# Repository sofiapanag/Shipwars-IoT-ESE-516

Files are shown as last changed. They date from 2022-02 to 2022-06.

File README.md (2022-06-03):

# SHIPWARS

## DEVPOST LINK
https://devpost.com/software/ship-wars

## Youtube LINK
https://www.youtube.com/watch?v=rYZES1QMRgo&feature=emb_imp_woyt

## Compilation
A recreation of battleship game using embedded system. The game can be played remotely by 2 players using identical hardware (PCBs) we designed.

For Altium PCB design files - refer to "Altium_design_Shipwars"

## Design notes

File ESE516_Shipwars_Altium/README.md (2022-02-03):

# ESE516_Starter_PCB
This is the starter PCB (Altium) for the class ESE516

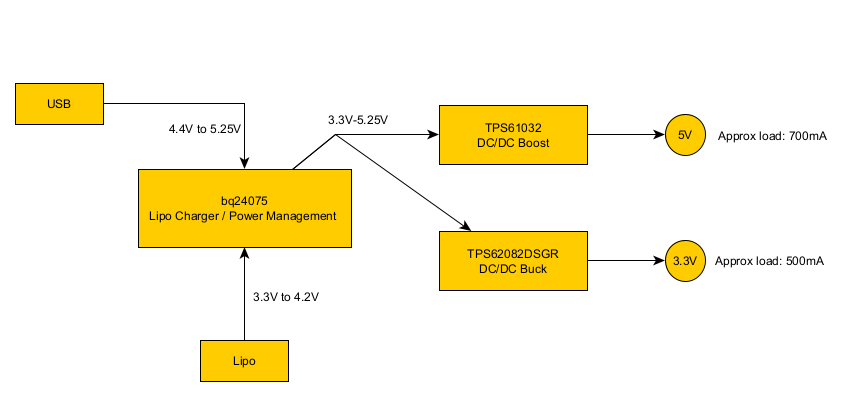
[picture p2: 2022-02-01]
Power_architect/power_management.png

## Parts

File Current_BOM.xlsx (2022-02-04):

Group Name
Group Member # 1 | Sofia Panagopoulou
Group Member # 2 | Pattana Soranasataporn
Component | Manufacturer part number (MPN) | Manufacturer | Digikey PN | Voltage(Min) | Voltage(Max) | Power - Current Consumption, typical (mA) | Quiescent current (mA) | Interface to MCU | Qty | Cost QTY1 | Cost QTY 1K | Dev Board Link (Required) | Dev Board Price | Comments | IN Altium lib?
MCU and WiFI | ATSAMW25H18-MR210PB1952 | microchip | ATSAMW25H18-MR210PB1952-ND | 2.7V | 4.3V | 230 | 0.02 | N/A | 2 | 12.05 | 10.92 | https://www.digikey.com/product-detail/en/microchip-technology/ATSAMW25-XPRO/ATSAMW25-XPRO-ND/5235960 | 41.04 |  | Provided
Adafruit NeoTrellis RGB Driver PCB for 4x4 Keypad | 3954 | Adafruit | 1528-2712-ND | 3.7V | 5.5V | 320 | 0 | I2C | 4 | 12.5 | 12.5 | https://www.digikey.com/en/products/detail/adafruit-industries-llc/3954/9658070 | 12.5 | External connect - not in PCB | External
LSM6DSO Accelero | LSM6DSOTR | STMicroelectronics | 497-18181-2-ND | 1.71V | 3.6V | 0.55 | 0 | I2C | 2 | 5.46 | N/A | https://www.digikey.com/en/products/detail/sparkfun-electronics/SEN-18020/14313960 | 11.95 |  | Y
 | GRM155R71C104KA88D | Murata | 490-3261-2-ND |  |  |  |  |  |  |  |  |  |  | any Generic Capacitor
Joystick, 2 - Axis Analog (Resistive) Output | COM-09032 | Sparkfun | 1528-1730-ND | 3.3V | 5V |  |  | 2x ADC, 1XGPIO | 2 | 3.95 | N/A | https://www.sparkfun.com/products/9110 | 1.95 |  | N - import from SnapEDA to Schematics.SchLib
Power
Lipo Charger | bq24075 | Texas Instrument | 296-38874-2-ND | 4.35V | 26V |  |  |  | 2 | 2.53 | 1.41 | https://www.digikey.com/en/products/detail/texas-instruments/BQ24075EVM/2047272 | 118.8 | Power | Y
DC/DC boost | TPS61032RSAR | Texas Instrument | 296-16662-2-ND | 1.8V | 5.5V |  |  |  | 2 | 3.13 | 1.95 | https://www.digikey.com/en/products/detail/texas-instruments/TPS61032EVM-208/562072 | 58.8 | Power | Y
 | C0603C105K8PACTU C0603C105K8PACTU | Kemet | 399-C0603C105K8PAC7867TR-ND |  |  |  |  |  | 1 |  |  |  |  |  | Y
 | C1608X5R1A156M080AC | TDK | 445-9117-2-ND |  |  |  |  |  | 1 |  |  |  |  |  | N - import from SnapEDA to CommonComponents.SchLib
 | GRM155R71A104KA01D | Murata | 490-6321-2-ND |  |  |  |  |  | 1 |  |  |  |  |  | Y
 | 6TPB470M | Panasonic | P16619CT-ND |  |  |  |  |  | 1 |  |  |  |  |  | N - import from SnapEDA to CommonComponents.SchLib
 | DR127-2R2-R | Eaton | 513-1220-1-ND |  |  |  |  |  | 1 |  |  |  |  |  | N - import from SnapEDA to CommonComponents.SchLib
 | RC0603FR-07390KL | Yageo | 311-390KHRTR-ND |  |  |  |  |  | 1 |  |  |  |  |  | N - import from SnapEDA to CommonComponents.SchLib
 | CRCW04022M15FKED | Vishay-Dale | 541-2.15MLCT-ND |  |  |  |  |  | 2 |  |  |  |  |  | Y
DC/DC buck | TPS62082DSGR | Texas Instrument | 296-49331-1-ND | 2.3V | 6V |  |  |  | 2 | 1.73 | 0.97 | N/A | N/A | Power | Y
 | GRJ155R60J106ME11D | Murata | 490-13211-1-ND |  |  |  |  |  |  |  |  |  |  |  | Y
 | GRM188R60J226MEA0D | Murata | 490-7611-2-ND |  |  |  |  |  |  |  |  |  |  |  | Y
 | 744311100 | Wurth Elektronik | 732-4177-1-ND |  |  |  |  |  |  |  |  |  |  |  | Y
 | RC0603FR-07178KL | Yageo | 311-178KHRCT-ND |  |  |  |  |  |  |  |  |  |  |  | Y
LiPo Battery | USE-702528-500PCBJST | US Electronics Inc. | 3544-USE-702528-500PCBJST-ND | 3V | 3.7V |  |  |  | 2 | 6.49 | 5.75 | N/A |  |  | External
Other peripherals
Piezoelectric Buzzers | PS1240P02BT | TDK Corporation | 445-2525-1-ND | 3V | 3V |  |  |  | 1 | 0.61 | N/A |  |  |  | N - import from SnapEDA to Schematics.SchLib
 | 2SC1815 | Central Semiconductor Corp | 1514-2SC1815PBFREE-ND |  |  |  |  |  |  |  |  |  |  | any 2SC1815 equivalent | N - import from SnapEDA to CommonComponents.SchLib
 |  |  |  |  | Total mA | 870.55 |  | Total |  | 120.68

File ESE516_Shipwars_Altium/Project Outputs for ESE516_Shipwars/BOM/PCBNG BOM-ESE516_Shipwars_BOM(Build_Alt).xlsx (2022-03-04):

Line # | Name | Description | Designator | Manufacturer 1 | Manufacturer Part Number 1 | Manufacturer Lifecycle 1 | Supplier 1 | Supplier Part Number 1 | Supplier Unit Price 1 | Supplier Subtotal 1 | Fitted
1 | PTS810 SJK 250 SMTR LFS | SWITCH TACTILE SPST-NO 0.05A 16V Tactile Switch SPST-NO Top Actuated Surface Mount | B1 | ITT C&K | PTS810SJM250SMTRLFS | Volume Production | Digi-Key | CKN10502CT-ND | 0 | 0 | Fitted
1 | PTS810 SJK 250 SMTR LFS | SWITCH TACTILE SPST-NO 0.05A 16V Tactile Switch SPST-NO Top Actuated Surface Mount | B3 | ITT C&K | PTS810SJM250SMTRLFS | Volume Production | Digi-Key | CKN10502CT-ND | 0 | 0 | Fitted
2 | CAP 100nF 16V 0603(1608) | CAP 100nF 16V ±10% 0603 (1608 Metric) Thickness 1mm SMD | C1 | Yageo | CC0603KPX7R7BB104 | Volume Production | Digi-Key | 311-1335-1-ND | 0.1 | 0.4 | Fitted
2 | CAP 100nF 16V 0603(1608) | CAP 100nF 16V ±10% 0603 (1608 Metric) Thickness 1mm SMD | C3 | Yageo | CC0603KPX7R7BB104 | Volume Production | Digi-Key | 311-1335-1-ND | 0.1 | 0.4 | Fitted
2 | CAP 100nF 16V 0603(1608) | CAP 100nF 16V ±10% 0603 (1608 Metric) Thickness 1mm SMD | C7 | Yageo | CC0603KPX7R7BB104 | Volume Production | Digi-Key | 311-1335-1-ND | 0.1 | 0.4 | Fitted
2 | CAP 100nF 16V 0603(1608) | CAP 100nF 16V ±10% 0603 (1608 Metric) Thickness 1mm SMD | C15 | Yageo | CC0603KPX7R7BB104 | Volume Production | Digi-Key | 311-1335-1-ND | 0.1 | 0.4 | Fitted
3 | C1608X5R1A226M080AC | Chip Capacitor, 22 uF, +/- 20%, 10 V, -55 to 85 degC, 0603 (1608 Metric), RoHS, Tape and Reel | C1bst | TDK | C1608X5R1A226M080AC | Volume Production | Digi-Key | 445-9077-2-ND | 0.11594 | 463.76 | Fitted
4 | CAP 10nF 16V 0603(1608) | CAP 10nF 16V ±10% 0603 (1608 Metric) Thickness 1mm SMD | C2 | Yageo | CC0603KRX7R7BB103 | Volume Production | Digi-Key | 311-3369-1-ND | 0.1 | 0.1 | Fitted
5 | GRM155R71A104KA01D | Chip Capacitor, 0.1 uF, +/- 10%, 10 V, -55 to 125 degC, 0402 (1005 Metric), RoHS, Tape and Reel | C2bst | Murata | GRM155R71A104KA01D | Unknown | Digi-Key | 490-6321-1-ND | 0.1 | 0.1 | Fitted
6 | C0603C105K8PACTU |  | C3bst | KEMET | C0603C105K8PACTU | Volume Production | Digi-Key | 399-C0603C105K8PAC7867CT-ND | 0.1 | 0.1 | Fitted
7 | CAP 4.7uF 16V 0805(2012) | CAP 4.7uF 16V -20% to +80% 0805 (2012 Metric) Thickness 1.45mm SMD | C4 | Yageo | CC0805ZKY5V7BB475 | Volume Production | Digi-Key | 311-1907-1-ND | 0.25 | 0.75 | Fitted
7 | CAP 4.7uF 16V 0805(2012) | CAP 4.7uF 16V -20% to +80% 0805 (2012 Metric) Thickness 1.45mm SMD | C25 | Yageo | CC0805ZKY5V7BB475 | Volume Production | Digi-Key | 311-1907-1-ND | 0.25 | 0.75 | Fitted
7 | CAP 4.7uF 16V 0805(2012) | CAP 4.7uF 16V -20% to +80% 0805 (2012 Metric) Thickness 1.45mm SMD | C26 | Yageo | CC0805ZKY5V7BB475 | Volume Production | Digi-Key | 311-1907-1-ND | 0.25 | 0.75 | Fitted
8 | 470uF 6.3V | Cap Tant Solid 470uF 6.3V D4 CASE 20% (7.3 X 4.3 X 3.8mm) 2917(7343) SMD 7343 0.035 Ohm 105 C Embossed T/R 6TPB470M | C4bst | Panasonic | 6TPB470M | Volume Production | Digi-Key | P16619CT-ND | 2.8 | 2.8 | Fitted
9 | CAP 47pF 16V 0603(1608) | CAP 47pF 16V ±0.5pF 0603 (1608 Metric) Thickness 1mm SMD | C5 | Yageo | CC0603KPX7R7BB473 | Volume Production | Digi-Key | 13-CC0603KPX7R7BB473CT-ND | 0.1 | 0.2 | Fitted
9 | CAP 47pF 16V 0603(1608) | CAP 47pF 16V ±0.5pF 0603 (1608 Metric) Thickness 1mm SMD | C6 | Yageo | CC0603KPX7R7BB473 | Volume Production | Digi-Key | 13-CC0603KPX7R7BB473CT-ND | 0.1 | 0.2 | Fitted
10 | CAP 10uF 16V 0805(2012) | CAP 10uF 16V ±10% 0805 (2012 Metric) Thickness 1.45mm SMD | C10 | Yageo | CC0805MKX7R7BB106 | Unknown | Digi-Key | 311-3508-1-ND | 0.64 | 1.28 | Fitted
10 | CAP 10uF 16V 0805(2012) | CAP 10uF 16V ±10% 0805 (2012 Metric) Thickness 1.45mm SMD | C11 | Yageo | CC0805MKX7R7BB106 | Unknown | Digi-Key | 311-3508-1-ND | 0.64 | 1.28 | Fitted
11 | CAP 1uF 16V 0603(1608) | CAP 1uF 16V ±5% 0603 (1608 Metric) Thickness 1mm SMD | C12 | Yageo | CC0603JRX7R7BB105 | Unknown | Digi-Key | 311-3485-2-ND | 0.0475 | 190 | Fitted
11 | CAP 1uF 16V 0603(1608) | CAP 1uF 16V ±5% 0603 (1608 Metric) Thickness 1mm SMD | C18 | Yageo | CC0603JRX7R7BB105 | Unknown | Digi-Key | 311-3485-2-ND | 0.0475 | 190 | Fitted
11 | CAP 1uF 16V 0603(1608) | CAP 1uF 16V ±5% 0603 (1608 Metric) Thickness 1mm SMD | C24 | Yageo | CC0603JRX7R7BB105 | Unknown | Digi-Key | 311-3485-2-ND | 0.0475 | 190 | Fitted
12 | CAP 18pF 16V 0603(1608) | CAP 18pF 16V ±5% 0603 (1608 Metric) Thickness 1mm SMD | C13 | KEMET | C0603C180J4GACTU | Volume Production | Digi-Key | 399-C0603C180J4GAC7867CT-ND | 0.25 | 0.5 | Fitted
12 | CAP 18pF 16V 0603(1608) | CAP 18pF 16V ±5% 0603 (1608 Metric) Thickness 1mm SMD | C14 | KEMET | C0603C180J4GACTU | Volume Production | Digi-Key | 399-C0603C180J4GAC7867CT-ND | 0.25 | 0.5 | Fitted
13 | CC0402KRX7R7BB104 | CAP CER 0.1UF 16V X7R 0402 | C16 | Yageo | CC0402KRX7R7BB104 | Volume Production | Digi-Key | 311-1338-2-ND | 0.00554 | 55.4 | Fitted
13 | CC0402KRX7R7BB104 | CAP CER 0.1UF 16V X7R 0402 | C17 | Yageo | CC0402KRX7R7BB104 | Volume Production | Digi-Key | 311-1338-2-ND | 0.00554 | 55.4 | Fitted
14 | 10uF 6.3V | Capacitor Ceramic Mlcc 0402 10UF 6.3V SMD | C8 | Murata | GRJ155R60J106ME11D | Volume Production | Digi-Key | 490-13211-1-ND | 0.2 | 0.2 | Fitted
15 | GRM188R60J226MEA0D | Chip Multilayer Ceramic Capacitors for General Purpose, 0603, 22uF, X5R, 15%, 20%, 6.3V | Coutbck | Murata | GRM188R60J226MEA0D | Volume Production | Digi-Key | 490-7611-2-ND | 0.0418 | 167.2 | Fitted
16 | PRTR5V0U2X,215 | Ultra Low Capacitance Double Rail-to-Rail ESD Protection Diode, 5.5 V, 1 pF, -40 to 85 degC, 4-Pin SOT143B, RoHS, Tape and Reel | D1 | Nexperia | PRTR5V0U2X,215 | Unknown | Mouser | 771-PRTR5V0U2X-T/R | 0.52 | 0.52 | Fitted
17 | LTST-C170CKT | LED Uni-Color Red, 100 mW, 200 mA, -55 to 85 degC, 2-Pin SMD, RoHS, Tape and Reel | D3 | Lumex | SML-LX0805SIC-TR | Volume Production | Digi-Key | 67-1636-1-ND | 0.61 | 1.83 | Fitted
17 | LTST-C170CKT | LED Uni-Color Red, 100 mW, 200 mA, -55 to 85 degC, 2-Pin SMD, RoHS, Tape and Reel | D5 | Lumex | SML-LX0805SIC-TR | Volume Production | Digi-Key | 67-1636-1-ND | 0.61 | 1.83 | Fitted
17 | LTST-C170CKT | LED Uni-Color Red, 100 mW, 200 mA, -55 to 85 degC, 2-Pin SMD, RoHS, Tape and Reel | DS3 | Lumex | SML-LX0805SIC-TR | Volume Production | Digi-Key | 67-1636-1-ND | 0.61 | 1.83 | Fitted
18 | LTST-C170GKT | LED Uni-Color Green, 100 mW, 120 mA, -55 to 85 degC, 2-Pin SMD, RoHS, Tape and Reel | D4 | Vishay Lite-On | LTST-C170GKT | Volume Production | Digi-Key | 160-1179-2-ND | 0.05267 | 158.01 | Fitted
18 | LTST-C170GKT | LED Uni-Color Green, 100 mW, 120 mA, -55 to 85 degC, 2-Pin SMD, RoHS, Tape and Reel | DS1 | Vishay Lite-On | LTST-C170GKT | Volume Production | Digi-Key | 160-1179-2-ND | 0.05267 | 158.01 | Fitted
18 | LTST-C170GKT | LED Uni-Color Green, 100 mW, 120 mA, -55 to 85 degC, 2-Pin SMD, RoHS, Tape and Reel | DS2 | Vishay Lite-On | LTST-C170GKT | Volume Production | Digi-Key | 160-1179-2-ND | 0.05267 | 158.01 | Fitted
19 | MPZ1608S300ATAH0 | FERRITE BEAD 30 OHM 0603 1LN | FB2 | Murata | BLM18PG300SN1D | Volume Production | Digi-Key | 490-1035-1-ND | 0.1 | 0.1 | Fitted
20 | BLM21PG221SN1D | Chip Ferrite Bead for Power Lines, 220 Ohm, 2000 mA, -55 to 125 degC, 2 x 1.25 x 1.05 mm SMD, Tape and Reel | FB1 | Bourns | MH2029-221Y | Volume Production | Digi-Key | MH2029-221YCT-ND | 0.1 | 0.1 | Fitted
21 | TPS61032RSAR | 5-V Output, 1-A, 96% Efficient Boost Converter w/20uA Iq in TSSOP-16 16-QFN -40 to 85 | U2 | Texas Instruments | TPS61032RSAR | Volume Production | Digi-Key | 296-16662-1-ND | 3.13 | 3.13 | Fitted
22 | ZX62R-B-5P | Connector; USBMicro-B,Reverse type, SMT; 5 Position; Right Angle | J1 | Hirose | ZX62R-B-5P(30) | Volume Production | Digi-Key | H125274CT-ND | 1.02 | 1.02 | Fitted
23 | S4B-PH-SM4-TB(LF)(SN) | JST (JAPAN SOLDERLESS TERMINALS) - S4B-PH-SM4-TB(LF)(SN) - Wire-To-Board Connector, 2 mm, 4 Contacts, Header, PH Series, Surface Mount, 1 Rows | J3 | JST | S4B-PH-SM4-TB(LF)(SN) | Volume Production | Digi-Key | 455-1751-2-ND | 0.38039 | 380.39 | Fitted
23 | S4B-PH-SM4-TB(LF)(SN) | JST (JAPAN SOLDERLESS TERMINALS) - S4B-PH-SM4-TB(LF)(SN) - Wire-To-Board Connector, 2 mm, 4 Contacts, Header, PH Series, Surface Mount, 1 Rows | J4 | JST | S4B-PH-SM4-TB(LF)(SN) | Volume Production | Digi-Key | 455-1751-2-ND | 0.38039 | 380.39 | Fitted
24 | 744311100 | SMD Flat Wire High Current Inductor WE-HCI, L=1.00 µH | L1bck | Wurth Electronics | 744311100 | Volume Production | Digi-Key | 732-4177-1-ND | 3.69 | 3.69 | Fitted
25 | 2.2uH | Ind Power Shielded Wirewound 2.2uH 20% 100KHz Ferrite 12.5A T/R DR127-2R2-R | L1bst | Eaton Cooper | DR127-2R2-R | Volume Production | Digi-Key | 513-1220-1-ND | 1.5 | 1.5 | Fitted
26 | PS1240P02BT | TDK - PS1240P02BT - BUZZER, PIEZO, 70DB, 12.2MM | LS | TDK | PS1240P02BT | Volume Production | Digi-Key | 445-2525-1-ND | 0.62 | 0.62 | Fitted
27 | 640456-3 | Male Header, Pitch 2.54 mm, 1 x 3 Position, Height 10.03 mm, Tail Length 3.56 mm, -55 to 105 degC | P1 | TE Connectivity | 640456-3 | Volume Production | Mouser | 571-6404563 | 0.2 | 0.2 | Fitted
28 | 50V 150mA | Transistor GP BJT NPN 50V 150mA 3-Pin TO-92 Box 2SC1815 | Q | Central Semiconductor | 2SC1815 PBFREE | Unknown | Digi-Key | 1514-2SC1815PBFREE-ND | 0.98 | 0.98 | Fitted
29 | 27R 1% 0603(1608) | 27R 0.1W 1% 0603 (1608 Metric) SMD | R1 | Yageo | RC0603FR-0727RL | Volume Production | Digi-Key | 311-27.0HRTR-ND | 0.00312 | 15.6 | Fitted
29 | 27R 1% 0603(1608) | 27R 0.1W 1% 0603 (1608 Metric) SMD | R2 | Yageo | RC0603FR-0727RL | Volume Production | Digi-Key | 311-27.0HRTR-ND | 0.00312 | 15.6 | Fitted
29 | 27R 1% 0603(1608) | 27R 0.1W 1% 0603 (1608 Metric) SMD | R8 | Yageo | RC0603FR-0727RL | Volume Production | Digi-Key | 311-27.0HRTR-ND | 0.00312 | 15.6 | Fitted
29 | 27R 1% 0603(1608) | 27R 0.1W 1% 0603 (1608 Metric) SMD | R9 | Yageo | RC0603FR-0727RL | Volume Production | Digi-Key | 311-27.0HRTR-ND | 0.00312 | 15.6 | Fitted
29 | 27R 1% 0603(1608) | 27R 0.1W 1% 0603 (1608 Metric) SMD | R10 | Yageo | RC0603FR-0727RL | Volume Production | Digi-Key | 311-27.0HRTR-ND | 0.00312 | 15.6 | Fitted
30 | RC0603FR-07178KL |  | R1bck | Yageo | RC0603FR-07178KL | Volume Production | Digi-Key | 311-178KHRCT-ND | 0.1 | 0.1 | Fitted
31 | CRCW04022M15FKED |  | R1bst | Stackpole Electronics | RMCF0402FT2M15 | Volume Production | Digi-Key | RMCF0402FT2M15CT-ND | 0.1 | 0.2 | Fitted
31 | CRCW04022M15FKED |  | R3bst | Stackpole Electronics | RMCF0402FT2M15 | Volume Production | Digi-Key | RMCF0402FT2M15CT-ND | 0.1 | 0.2 | Fitted
32 | 390K 1% 0603(1608) | 390K 0.1W 1% 0603 (1608 Metric) SMD | R2bst | Yageo | RC0603FR-07390KL | Volume Production | Digi-Key | 311-390KHRCT-ND | 0.1 | 0.1 | Fitted
33 | 1K 1% 0603(1608) | 1K 0.1W 1% 0603 (1608 Metric) SMD | R3 | Stackpole Electronics | RMCF0603FT1K00 | Volume Production | Digi-Key | RMCF0603FT1K00TR-ND | 0.00218 | 10.9 | Fitted
33 | 1K 1% 0603(1608) | 1K 0.1W 1% 0603 (1608 Metric) SMD | R5 | Stackpole Electronics | RMCF0603FT1K00 | Volume Production | Digi-Key | RMCF0603FT1K00TR-ND | 0.00218 | 10.9 | Fitted
33 | 1K 1% 0603(1608) | 1K 0.1W 1% 0603 (1608 Metric) SMD | R6 | Stackpole Electronics | RMCF0603FT1K00 | Volume Production | Digi-Key | RMCF0603FT1K00TR-ND | 0.00218 | 10.9 | Fitted
33 | 1K 1% 0603(1608) | 1K 0.1W 1% 0603 (1608 Metric) SMD | R7 | Stackpole Electronics | RMCF0603FT1K00 | Volume Production | Digi-Key | RMCF0603FT1K00TR-ND | 0.00218 | 10.9 | Fitted
33 | 1K 1% 0603(1608) | 1K 0.1W 1% 0603 (1608 Metric) SMD | R15 | Stackpole Electronics | RMCF0603FT1K00 | Volume Production | Digi-Key | RMCF0603FT1K00TR-ND | 0.00218 | 10.9 | Fitted
33 | 1K 1% 0603(1608) | 1K 0.1W 1% 0603 (1608 Metric) SMD | R16 | Stackpole Electronics | RMCF0603FT1K00 | Volume Production | Digi-Key | RMCF0603FT1K00TR-ND | 0.00218 | 10.9 | Fitted
33 | 1K 1% 0603(1608) | 1K 0.1W 1% 0603 (1608 Metric) SMD | R18 | Stackpole Electronics | RMCF0603FT1K00 | Volume Production | Digi-Key | RMCF0603FT1K00TR-ND | 0.00218 | 10.9 | Fitted
33 | 1K 1% 0603(1608) | 1K 0.1W 1% 0603 (1608 Metric) SMD | R19 | Stackpole Electronics | RMCF0603FT1K00 | Volume Production | Digi-Key | RMCF0603FT1K00TR-ND | 0.00218 | 10.9 | Fitted
33 | 1K 1% 0603(1608) | 1K 0.1W 1% 0603 (1608 Metric) SMD | R24 | Stackpole Electronics | RMCF0603FT1K00 | Volume Production | Digi-Key | RMCF0603FT1K00TR-ND | 0.00218 | 10.9 | Fitted
33 | 1K 1% 0603(1608) | 1K 0.1W 1% 0603 (1608 Metric) SMD | R37 | Stackpole Electronics | RMCF0603FT1K00 | Volume Production | Digi-Key | RMCF0603FT1K00TR-ND | 0.00218 | 10.9 | Fitted
34 | Jumper 0603(1608) | Jumper 0603 (1608 Metric) | R4 | Stackpole Electronics | RMCF0603ZT0R00 | Volume Production | Avnet | RMCF0603ZT0R00 | 0.00142 | 7.1 | Fitted
34 | Jumper 0603(1608) | Jumper 0603 (1608 Metric) | R22 | Stackpole Electronics | RMCF0603ZT0R00 | Volume Production | Avnet | RMCF0603ZT0R00 | 0.00142 | 7.1 | Fitted
34 | Jumper 0603(1608) | Jumper 0603 (1608 Metric) | R23 | Stackpole Electronics | RMCF0603ZT0R00 | Volume Production | Avnet | RMCF0603ZT0R00 | 0.00142 | 7.1 | Fitted
34 | Jumper 0603(1608) | Jumper 0603 (1608 Metric) | R25 | Stackpole Electronics | RMCF0603ZT0R00 | Volume Production | Avnet | RMCF0603ZT0R00 | 0.00142 | 7.1 | Fitted
34 | Jumper 0603(1608) | Jumper 0603 (1608 Metric) | R27 | Stackpole Electronics | RMCF0603ZT0R00 | Volume Production | Avnet | RMCF0603ZT0R00 | 0.00142 | 7.1 | Fitted
34 | Jumper 0603(1608) | Jumper 0603 (1608 Metric) | R28 | Stackpole Electronics | RMCF0603ZT0R00 | Volume Production | Avnet | RMCF0603ZT0R00 | 0.00142 | 7.1 | Fitted
34 | Jumper 0603(1608) | Jumper 0603 (1608 Metric) | R31 | Stackpole Electronics | RMCF0603ZT0R00 | Volume Production | Avnet | RMCF0603ZT0R00 | 0.00142 | 7.1 | Fitted
34 | Jumper 0603(1608) | Jumper 0603 (1608 Metric) | R33 | Stackpole Electronics | RMCF0603ZT0R00 | Volume Production | Avnet | RMCF0603ZT0R00 | 0.00142 | 7.1 | Fitted
35 | 10K 1% 0603(1608) | 10K 0.1W 1% 0603 (1608 Metric) SMD | R11 | Stackpole Electronics | RMCF0603FT10K0 | Volume Production | Digi-Key | RMCF0603FT10K0TR-ND | 0.00218 | 10.9 | Fitted
35 | 10K 1% 0603(1608) | 10K 0.1W 1% 0603 (1608 Metric) SMD | R13 | Stackpole Electronics | RMCF0603FT10K0 | Volume Production | Digi-Key | RMCF0603FT10K0TR-ND | 0.00218 | 10.9 | Fitted
35 | 10K 1% 0603(1608) | 10K 0.1W 1% 0603 (1608 Metric) SMD | R14 | Stackpole Electronics | RMCF0603FT10K0 | Volume Production | Digi-Key | RMCF0603FT10K0TR-ND | 0.00218 | 10.9 | Fitted
35 | 10K 1% 0603(1608) | 10K 0.1W 1% 0603 (1608 Metric) SMD | R17 | Stackpole Electronics | RMCF0603FT10K0 | Volume Production | Digi-Key | RMCF0603FT10K0TR-ND | 0.00218 | 10.9 | Fitted
35 | 10K 1% 0603(1608) | 10K 0.1W 1% 0603 (1608 Metric) SMD | R26 | Stackpole Electronics | RMCF0603FT10K0 | Volume Production | Digi-Key | RMCF0603FT10K0TR-ND | 0.00218 | 10.9 | Fitted
35 | 10K 1% 0603(1608) | 10K 0.1W 1% 0603 (1608 Metric) SMD | R29 | Stackpole Electronics | RMCF0603FT10K0 | Volume Production | Digi-Key | RMCF0603FT10K0TR-ND | 0.00218 | 10.9 | Fitted
35 | 10K 1% 0603(1608) | 10K 0.1W 1% 0603 (1608 Metric) SMD | R30 | Stackpole Electronics | RMCF0603FT10K0 | Volume Production | Digi-Key | RMCF0603FT10K0TR-ND | 0.00218 | 10.9 | Fitted
35 | 10K 1% 0603(1608) | 10K 0.1W 1% 0603 (1608 Metric) SMD | R32 | Stackpole Electronics | RMCF0603FT10K0 | Volume Production | Digi-Key | RMCF0603FT10K0TR-ND | 0.00218 | 10.9 | Fitted
35 | 10K 1% 0603(1608) | 10K 0.1W 1% 0603 (1608 Metric) SMD | R34 | Stackpole Electronics | RMCF0603FT10K0 | Volume Production | Digi-Key | RMCF0603FT10K0TR-ND | 0.00218 | 10.9 | Fitted
35 | 10K 1% 0603(1608) | 10K 0.1W 1% 0603 (1608 Metric) SMD | R36 | Stackpole Electronics | RMCF0603FT10K0 | Volume Production | Digi-Key | RMCF0603FT10K0TR-ND | 0.00218 | 10.9 | Fitted
35 | 10K 1% 0603(1608) | 10K 0.1W 1% 0603 (1608 Metric) SMD | R38 | Stackpole Electronics | RMCF0603FT10K0 | Volume Production | Digi-Key | RMCF0603FT10K0TR-ND | 0.00218 | 10.9 | Fitted
36 | 100R 1% 0603(1608) | 100R 0.1W 1% 0603 (1608 Metric) SMD | R12 | Bourns | CR0603-FX-1000ELF | Volume Production | Digi-Key | CR0603-FX-1000ELFTR-ND | 0.00218 | 10.9 | Fitted
36 | 100R 1% 0603(1608) | 100R 0.1W 1% 0603 (1608 Metric) SMD | R35 | Bourns | CR0603-FX-1000ELF | Volume Production | Digi-Key | CR0603-FX-1000ELFTR-ND | 0.00218 | 10.9 | Fitted
37 | 1K13 1% 0603(1608) | 1K13 0.1W 1% 0603 (1608 Metric) SMD | R20 | Stackpole Electronics | RMCF0603FT1K13 | Volume Production | Digi-Key | RMCF0603FT1K13CT-ND | 0.017 | 0.17 | Fitted
37 | 1K13 1% 0603(1608) | 1K13 0.1W 1% 0603 (1608 Metric) SMD | R21 | Stackpole Electronics | RMCF0603FT1K13 | Volume Production | Digi-Key | RMCF0603FT1K13CT-ND | 0.017 | 0.17 | Fitted
38 | ADA_2765 | Mini 2-Axis Analog Thumbstick | S1 | Adafruit Industries | 2765 | Volume Production | Digi-Key | 1528-1730-ND | 2.5 | 2.5 | Fitted
39 | 104031-0811 | Micro SD Card, RA, -25 to 85 degC, 8-Pin SMD, RoHS, Tape and Reel | SD1 | Molex | 1040310811 | Volume Production | Digi-Key | WM6357TR-ND | 1.14 | 2278.28 | Fitted
40 | FT234XD-R | FT234XD USB to BASIC UART IC, -40 to +85 degC, 12-Pin DFN, Pb-Free, Tape and Reel | U1 | FTDI | FT234XD-R | Volume Production |  |  |  |  | Fitted
41 | 20021111-00010T4LF | CONN HEADER 10POS UNSHD VERT T/H | U3 | Amphenol ICC / FCI | 20021111-00010T4LF | Unknown | Mouser | 649-221111-00010T4LF | 0.74 | 0.74 | Fitted
42 | SAMW25H18-MR510PB | RF TXRX MODULE WIFI TRACE ANT | U4 | Microchip | ATSAMW25H18-MR510PB | Unknown | Digikey | ATSAMW25H18-MR510PB-ND |  |  | Fitted
43 | BQ24075RGTRG4 | USB-Friendly Li-Ion Battery Charger and Power-Path Management IC, Vout 5.5 V, 4.3 V, -40 to 85 degC, 16-pin QFN (RGT), Green (RoHS & no Sb/Br) | U6 | Texas Instruments | BQ24079TRGTT | Volume Production | Digi-Key | 296-BQ24079TRGTTCT-ND | 3.03 | 3.03 | Fitted
44 | TPS62082DSGR | Buck Step Down Regulator with 2.3 to 6 V Input and 3.3 V Output, -40 to 85 degC, 8-Pin WSON (DSG), Green (RoHS & no Sb/Br) | U7 | Texas Instruments | TPS62082DSGR | Volume Production | Digi-Key | 296-49331-1-ND | 1.73 | 1.73 | Fitted
45 | LSM6DSOTR | CONSUMER MEMS | U8 | STMicroelectronics | LSM6DSOTR | Unknown |  |  |  |  | Fitted
46 | ABS07-32.768KHz-T | Crystal, 32.768 kHz, 12.5 pF, -40 to 85 degC, SMD Low Profile 3.2 x 1.5 x 0.9 mm, Tape and Reel | X1 | Abracon | ABS07-32.768KHZ-T | Volume Production | Digi-Key | 535-9542-2-ND | 0.6808 | 2042.4 | Fitted

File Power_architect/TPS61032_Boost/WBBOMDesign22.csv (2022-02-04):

Part | Manufacturer | Part Number | Quantity | Price ($) | Footprint (mm²) | Description
Coutx | Kemet | C0603C105K8PACTU | 1 | 0.01 | 4.68 | Cap: 1 µF Total Derated Cap: 950 nF VDC: 10 V ESR: 1 mΩ Package: 0603
Cin | TDK | C1608X5R1A156M080AC | 1 | 0.12 | 4.68 | Cap: 15 µF Total Derated Cap: 3.7 µF VDC: 10 V ESR: 6.53 mΩ Package: 0603
Cinx | MuRata | GRM155R71A104KA01D | 1 | 0.01 | 3 | Cap: 100 nF Total Derated Cap: 100 nF VDC: 10 V ESR: 1 mΩ Package: 0402
Cout | Panasonic | 6TPB470M | 1 | 0.96 | 58.59 | Cap: 470 µF Total Derated Cap: 470 µF VDC: 6.3 V ESR: 35 mΩ Package: 7343-40
L1 | Coiltronics | DR127-2R2-R | 1 | 0.84 | 210.25 | L: 2.2 µH DCR: 4.02 mΩ IDC: 12.5 A
Rlbb | Yageo | RC0603FR-07390KL | 1 | 0.01 | 4.68 | Resistance: 390 kΩ Tolerance: 1.0% Power: 100 mW
Rlbo | Vishay-Dale | CRCW04022M15FKED | 1 | 0.01 | 3 | Resistance: 2.15 MΩ Tolerance: 1.0% Power: 63 mW
Rlbt | Vishay-Dale | CRCW04022M15FKED | 1 | 0.01 | 3 | Resistance: 2.15 MΩ Tolerance: 1.0% Power: 63 mW
U1 | Texas Instruments | TPS61032PWPR | 1 | 1.113 | 58.8

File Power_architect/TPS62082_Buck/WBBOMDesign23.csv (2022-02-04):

Part | Manufacturer | Part Number | Quantity | Price ($) | Footprint (mm²) | Description
Cin | MuRata | GRJ155R60J106ME11D | 1 | 0.02 | 3 | Cap: 10 µF Total Derated Cap: 2 µF VDC: 6.3 V ESR: 1 mΩ Package: 0402
Cout | MuRata | GRM188R60J226MEA0D | 1 | 0.05 | 4.68 | Cap: 22 µF Total Derated Cap: 7.9 µF VDC: 6.3 V ESR: 1 mΩ Package: 0603
L1 | Wurth Elektronik | 744311100 | 1 | 2.55 | 80.1 | L: 1 µH DCR: 5.06 mΩ IDC: 15 A
Rpg | Yageo | RC0603FR-07178KL | 1 | 0.01 | 4.68 | Resistance: 178 kΩ Tolerance: 1.0% Power: 100 mW
U1 | Texas Instruments | TPS62082DSGR | 1 | 0.552 | 9.61

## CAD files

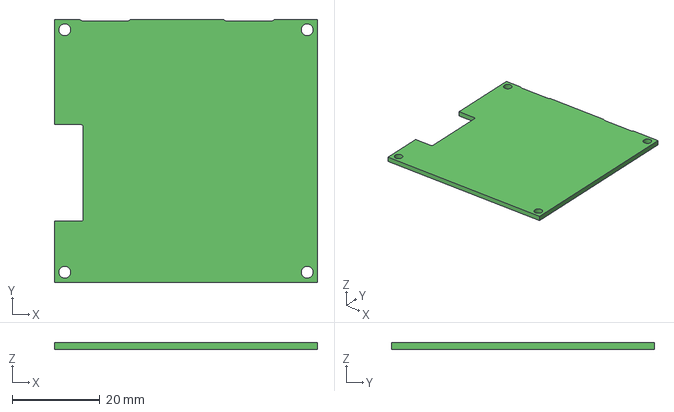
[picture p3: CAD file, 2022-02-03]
ESE516_Shipwars_Altium/Extras/BoardShape 50mmx50mm.step
60.0 x 60.0 x 1.53 mm

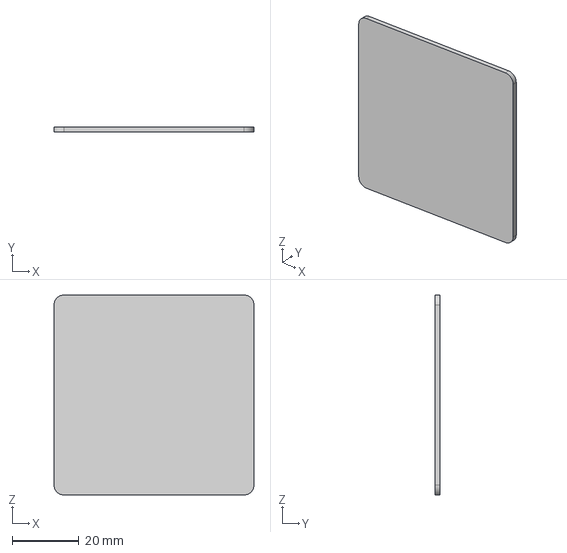
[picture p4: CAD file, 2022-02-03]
ESE516_Shipwars_Altium/Extras/BoardShape_60x60_mm.step
60.0 x 1.57 x 60.0 mm

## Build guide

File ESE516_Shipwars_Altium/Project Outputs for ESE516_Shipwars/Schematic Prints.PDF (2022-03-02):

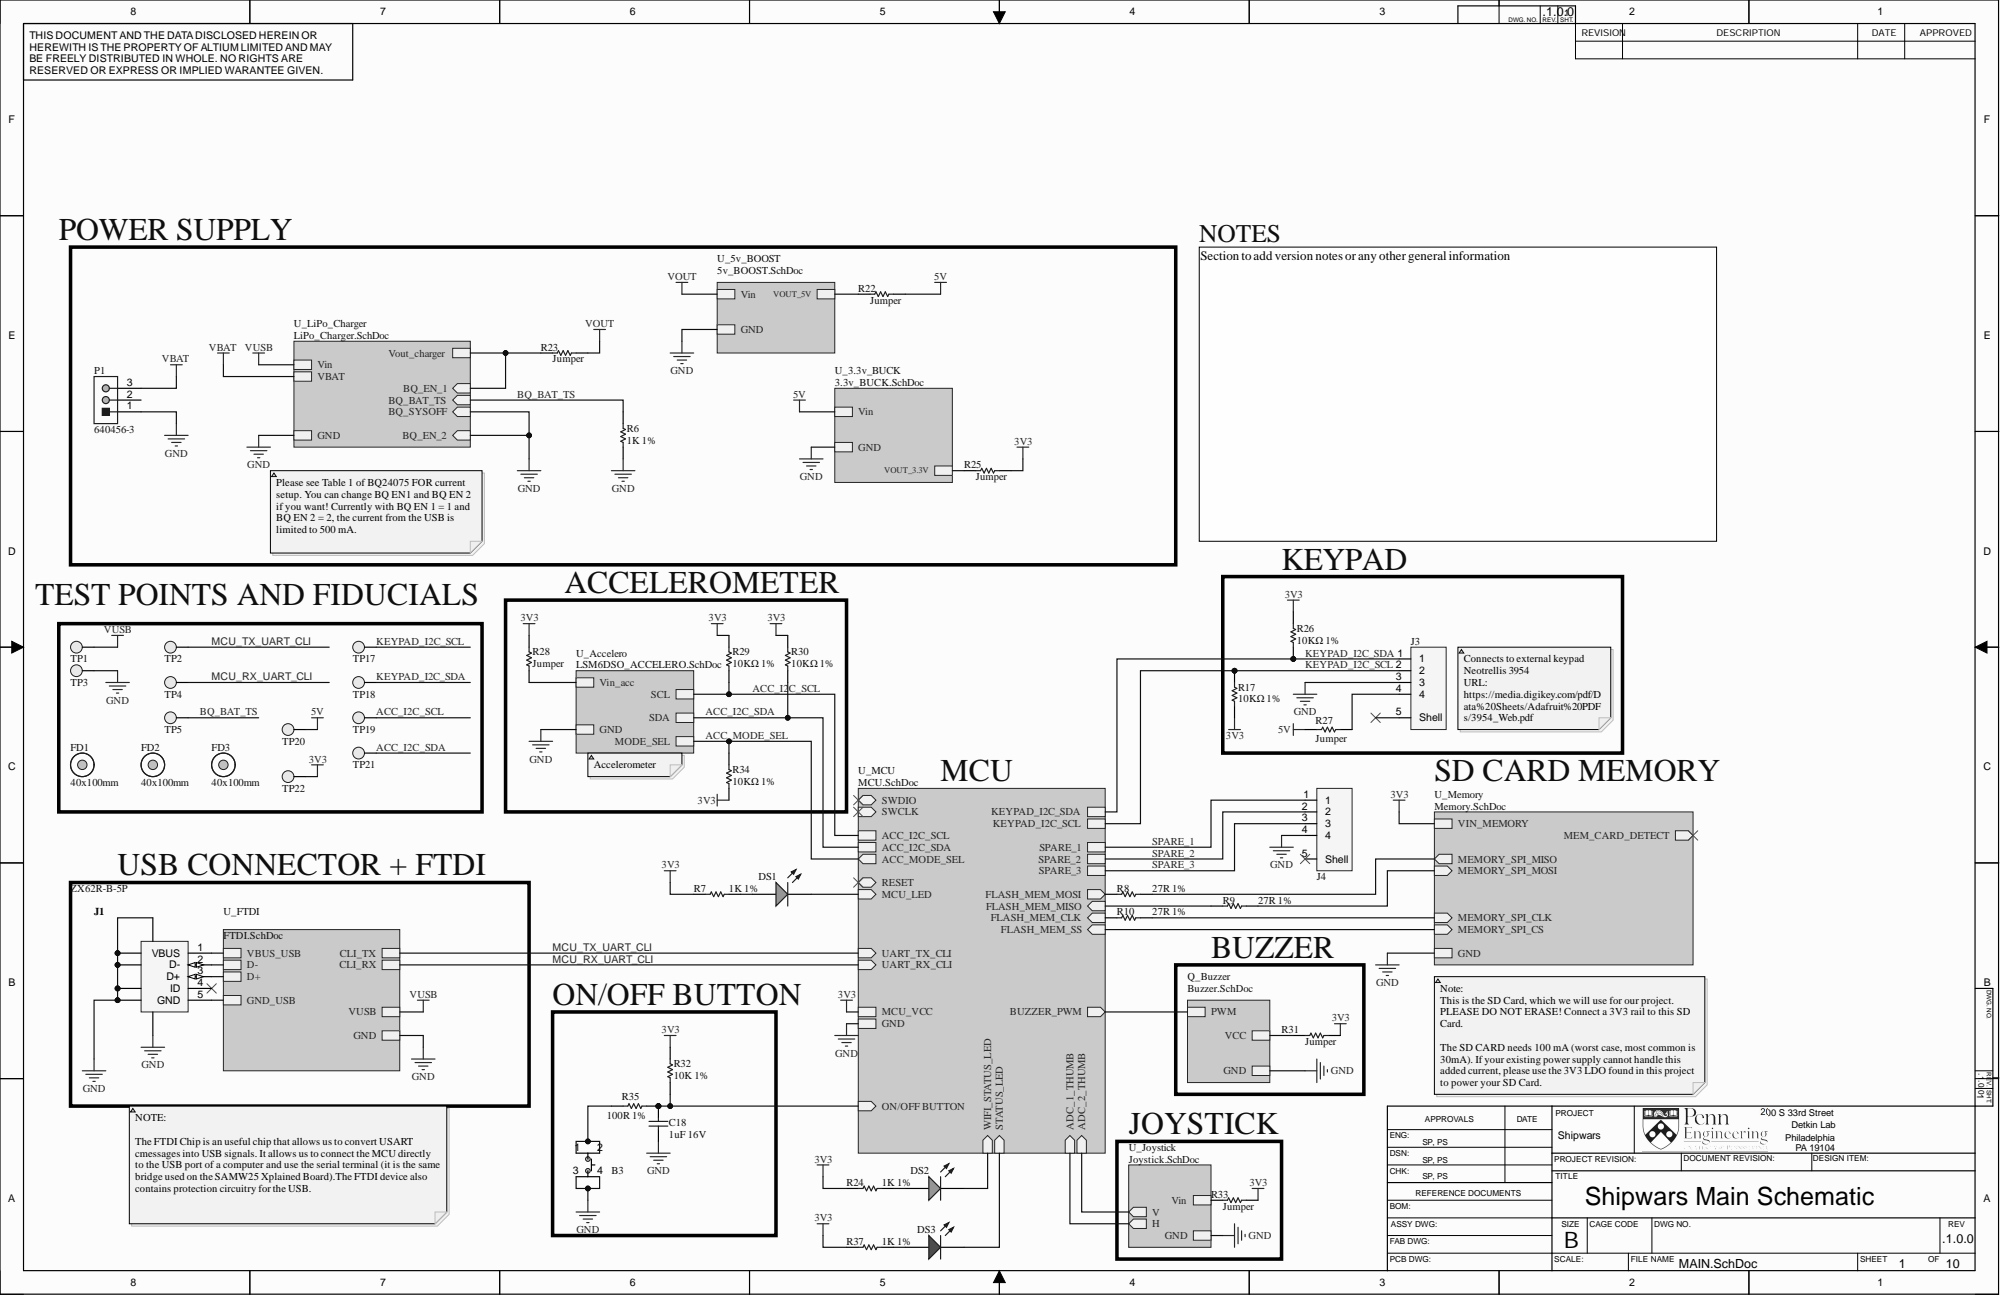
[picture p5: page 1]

DWG. NO. | REV. | SHT.

THIS DOCUMENT AND THE DATA DISCLOSED HEREIN OR HEREWITH IS THE PROPERTY OF ALTIUM LIMITED AND MAY BE FREELY DISTRIBUTED IN WHOLE. NO RIGHTS ARE RESERVED OR EXPRESS OR IMPLIED WARANTEE GIVEN. | NOTES | REVISION | DESCRIPTION | DATE | APPROVED

Section to add version notes or any other general information

GND
Please see Table 1 of BQ24075 FOR current
setup. You can change BQ EN1 and BQ EN 2
if you want! Currently with BQ EN 1 = 1 and
BQ EN 2 = 2, the current from the USB is
limited to 500 mA.

TEST POINTS AND FIDUCIALS

KEYPAD_I2C_SCL | 2 2

Connects to external keypad
Neotrellis 3954
URL:
https://media.digikey.com/pdf/D
ata%20Sheets/Adafruit%20PDF
s/3954_Web.pdf

Note:
This is the SD Card, which we will use for our project.
PLEASE DO NOT ERASE! Connect a 3V3 rail to this SD
Card.

REV. SHT. DWG. NO.

The SD CARD needs 100 mA (worst case, most common is
30mA). If your existing power supply cannot handle this
added current, please use the 3V3 LDO found in this project
to power your SD Card.

DATE | PROJECT Shipwars | 200 S 33rd Street Detkin Lab APPROVALS Philadelphia PA 19104

ENG: SP, PS

The FTDI Chip is an useful chip that allows us to convert USART
cmessages into USB signals. It allows us to connect the MCU directly
to the USB port of a computer and use the serial terminal (it is the same
bridge used on the SAMW25 Xplained Board).The FTDI device also
contains protection circuitry for the USB.

DSN: SP, PS

PROJECT REVISION: | DOCUMENT REVISION: | DESIGN ITEM:

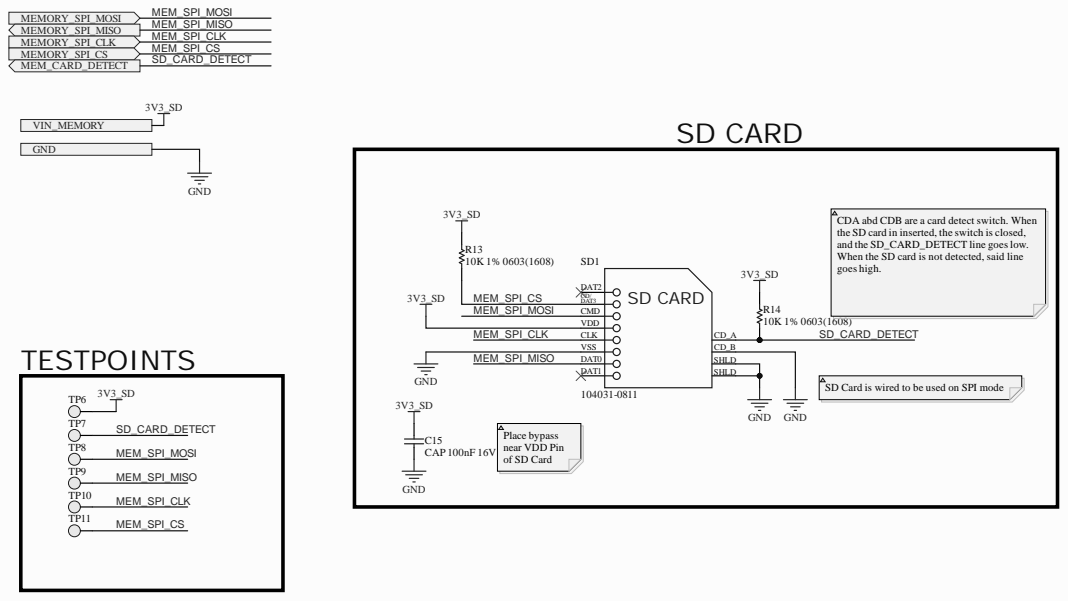
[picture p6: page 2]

DWG . N O . | R E . | S T.

T IS DOC U MEN T AN D T HE D ATA D ISCLOSED HEREI N OR HEREW I T IS T HE PROPER TY OF ALT I U M LI M I TED AN D M AY BE F REELY D IST R IBU TED I N W HOLE. NO R IGH TS ARE RESERVED OR EXPRESS OR I MPLIED WARAN TEE GIVEN . | MEM_SPI MEMO RY _SPI_ M O S I MEM_SPI MEMO RY _SPI_ M I S O MEM_SPI MEMO RY _SPI_ C LK MEM_SPI MEMO RY _SPI_ C S SD_CAR MEM_CARD _ D E T E C T 3 V 3 _ S D SD CARD | REVISI O | N DESC R IPT I O N | DAT E | APPR OVED

REV. SHT. DWG. NO.

DATE | PRO JECT Shipw a rs | 2 0 0 S 3 3rd Stre e t b APPROVALS D e tki n L a Ph i l a d e l p h i a PA 1 9 1 0 4

ENG : SP, PS

DSN: SP, PS

PRO JECT REVISION: | DOCUMENT REVISION: | DESIGN ITEM :

CHK: SP, PS

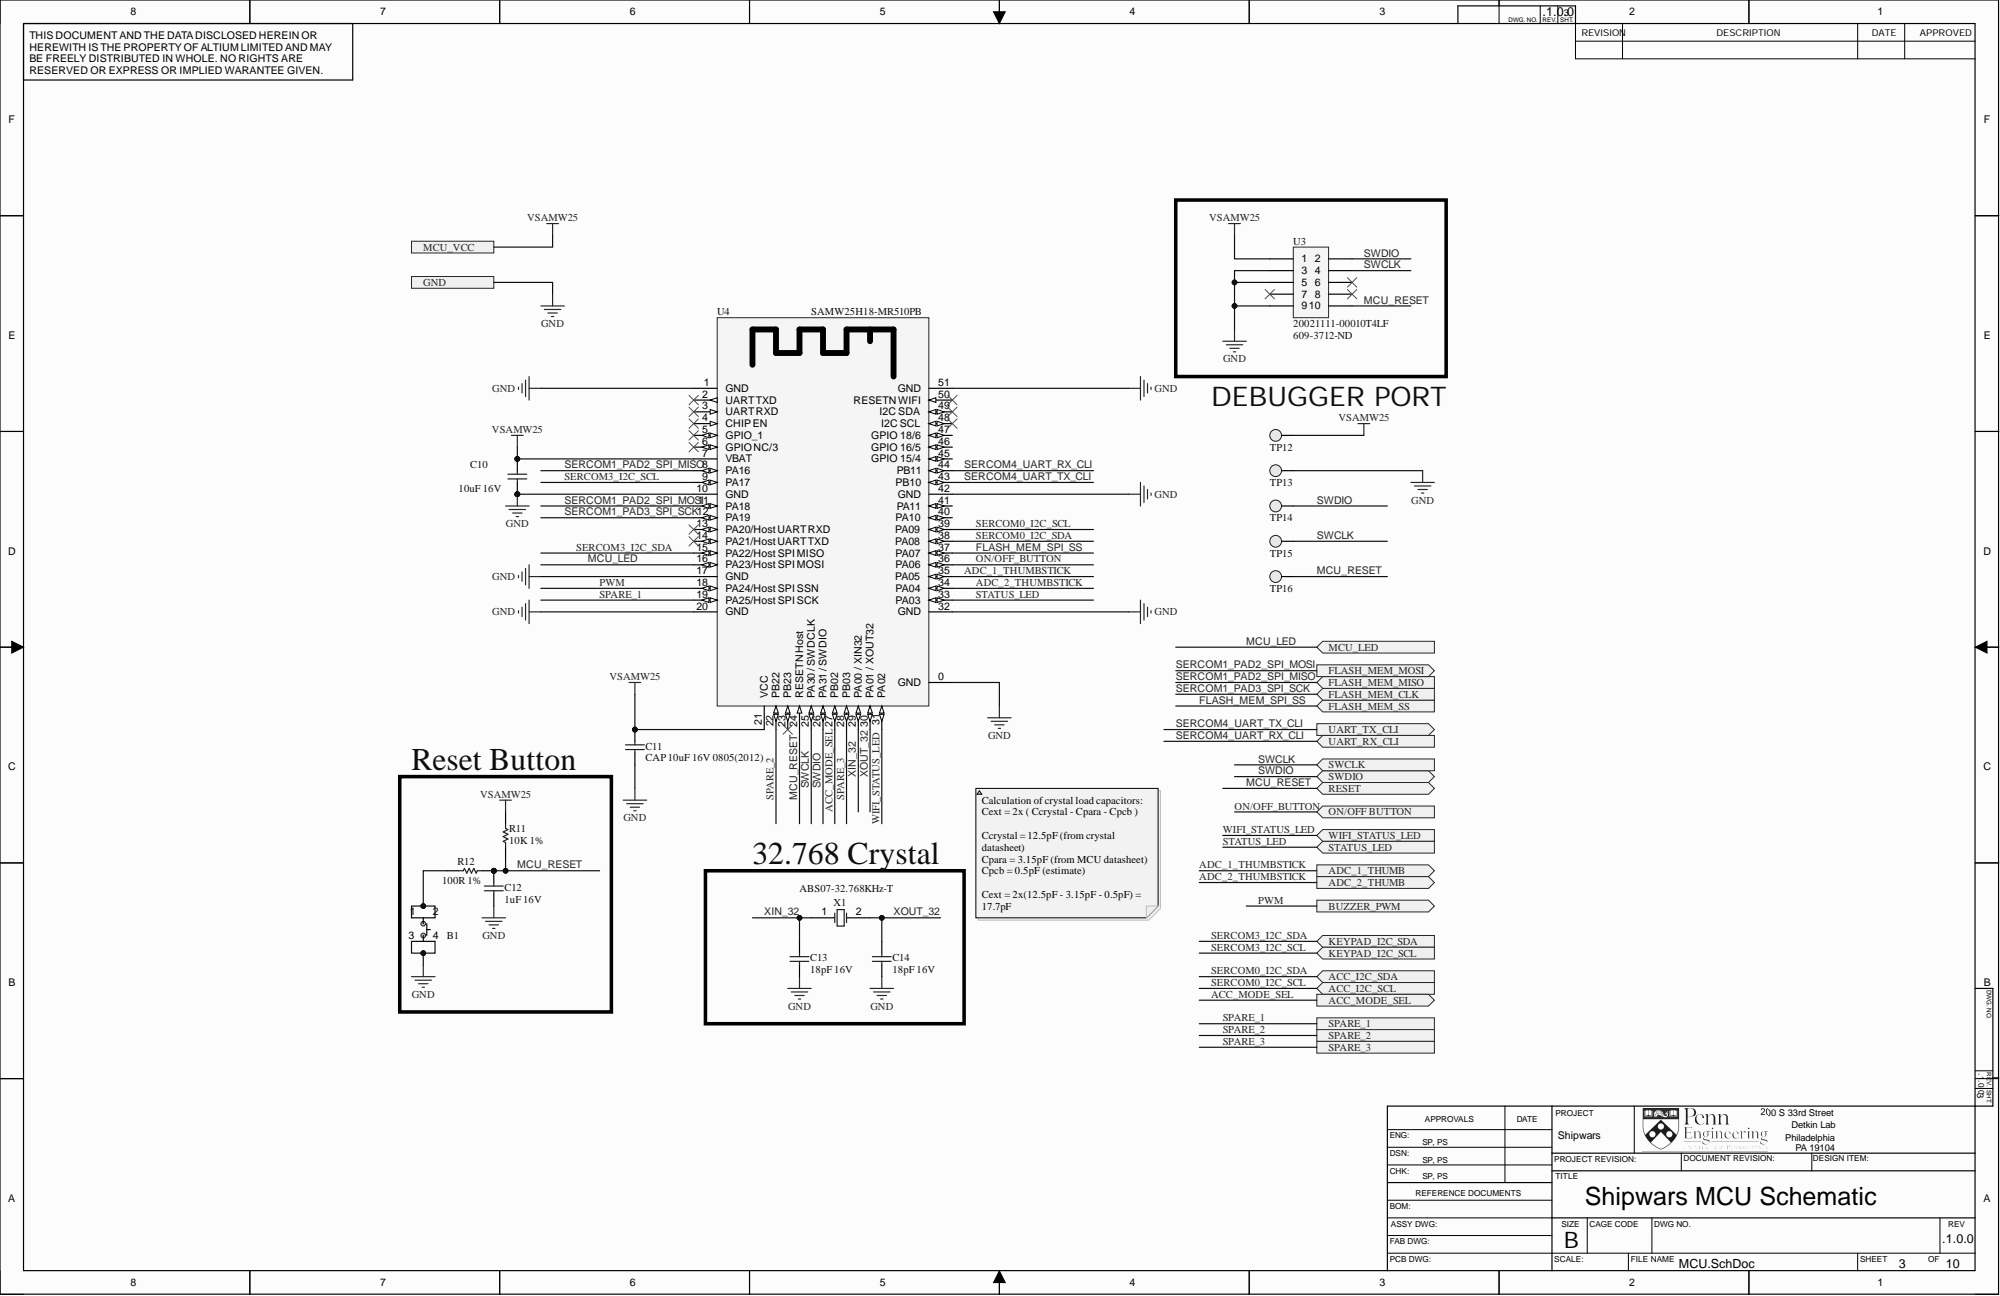
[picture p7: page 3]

Calculation of crystal load capacitors:
Cext = 2x ( Ccrystal - Cpara - Cpcb )

ON/OFF BUTTON ON/OFF_BUTTON

Ccrystal = 12.5pF (from crystal
datasheet)
Cpara = 3.15pF (from MCU datasheet)
Cpcb = 0.5pF (estimate)

REV. SHT. DWG. NO.

DATE | PROJECT Shipwars | 200 S 33rd Street Detkin Lab APPROVALS Philadelphia PA 19104

ENG: SP, PS

DSN: SP, PS

PROJECT REVISION: | DOCUMENT REVISION: | DESIGN ITEM:

CHK: SP, PS

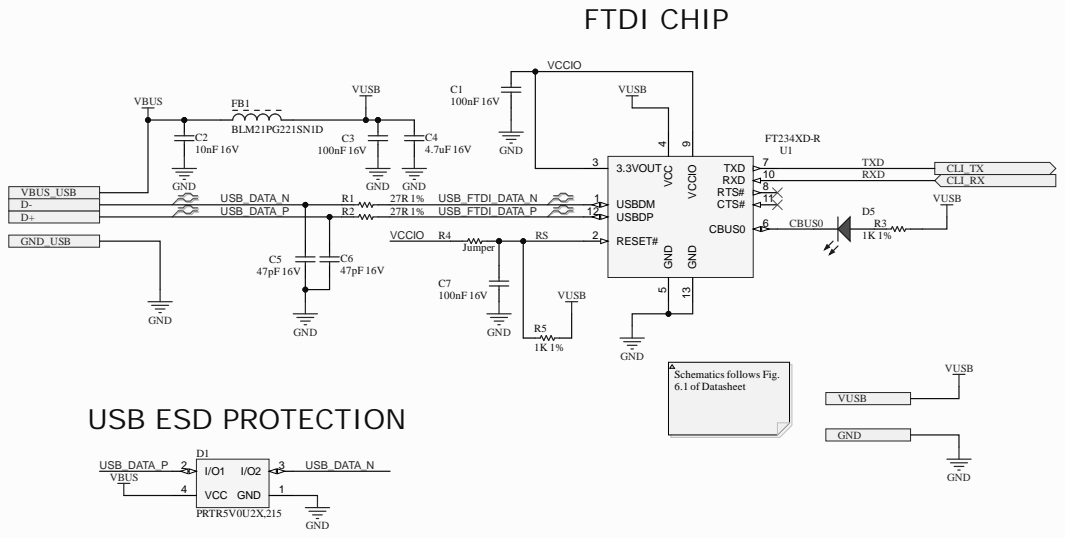
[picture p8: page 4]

REV. SHT. DWG. NO.

DATE | PROJECT Shipwars | 200 S 33rd Street Detkin Lab APPROVALS Philadelphia PA 19104

ENG: SP, PS

DSN: SP, PS

PROJECT REVISION: | DOCUMENT REVISION: | DESIGN ITEM:

CHK: SP, PS

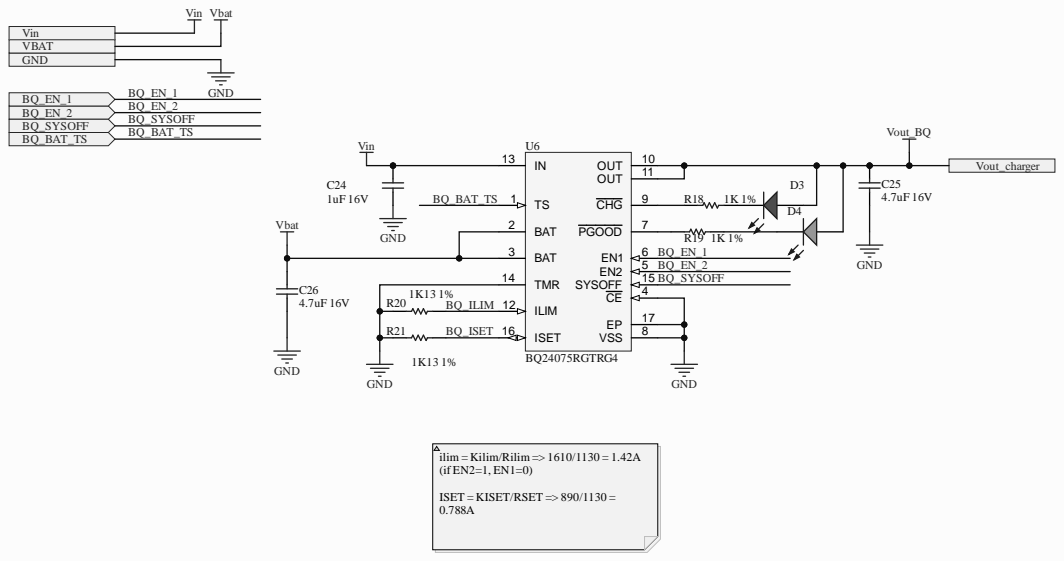
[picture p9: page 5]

DWG . N O . | R E . | S T.

T IS DOC U MEN T AN D T HE D ATA D ISCLOSED HEREI N OR HEREW I T IS T HE PROPER TY OF ALT I U M LI M I TED AN D M AY BE F REELY D IST R IBU TED I N W HOLE. NO R IGH TS ARE RESERVED OR EXPRESS OR I MPLIED WARAN TEE GIVEN . | Vi n V b | REVISI O | N DESC R IPT I O N | DAT E | APPR OVED

1 K 1 3 1 % R2 0 BQ _ILIM

REV. SHT. DWG. NO.

DATE | PRO JECT Shipw a rs | 2 0 0 S 3 3rd Stre e t b APPROVALS D e tki n L a Ph i l a d e l p h i a PA 1 9 1 0 4

ENG : SP, PS

DSN: SP, PS

PRO JECT REVISION: | DOCUMENT REVISION: | DESIGN ITEM :

CHK: SP, PS

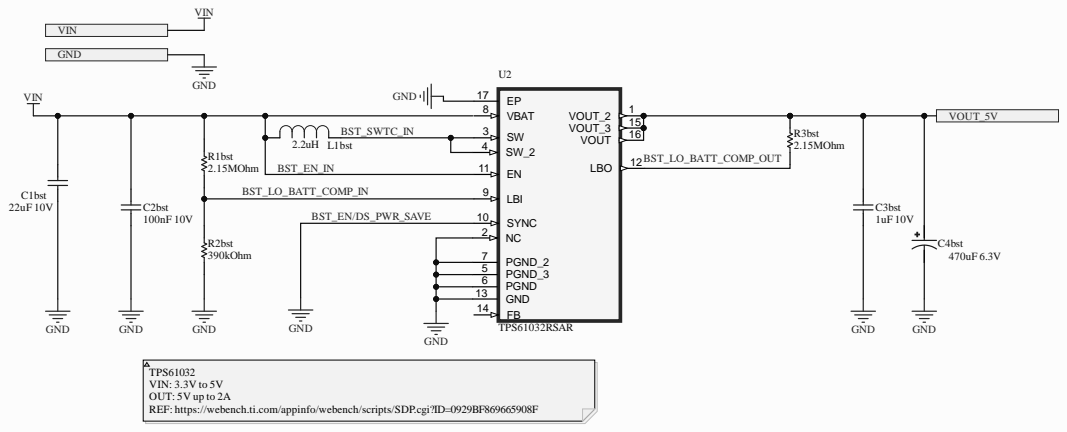
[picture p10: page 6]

PGND_2 7
PGND_3 5
PGND 6

TPS61032
VIN: 3.3V to 5V
OUT: 5V up to 2A
REF: https://webench.ti.com/appinfo/webench/scripts/SDP.cgi?ID=0929BF869665908F

REV. SHT. DWG. NO.

DATE | PROJECT Shipwars | 200 S 33rd Street Detkin Lab APPROVALS Philadelphia PA 19104

ENG: SP, PS

DSN: SP, PS

PROJECT REVISION: | DOCUMENT REVISION: | DESIGN ITEM:

CHK: SP, PS

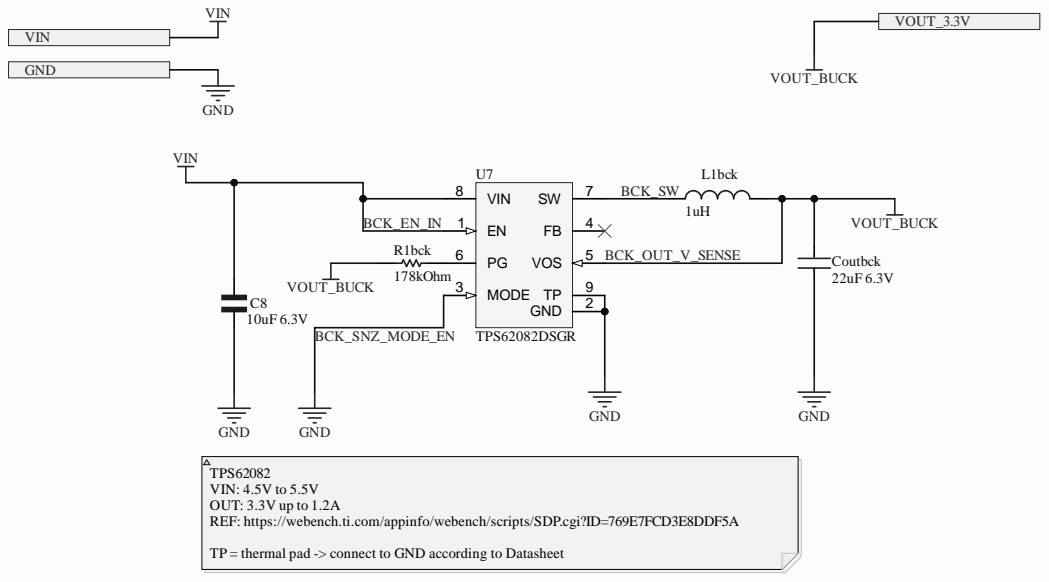
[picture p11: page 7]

TPS62082
VIN: 4.5V to 5.5V
OUT: 3.3V up to 1.2A
REF: https://webench.ti.com/appinfo/webench/scripts/SDP.cgi?ID=769E7FCD3E8DDF5A

TP = thermal pad -> connect to GND according to Datasheet

REV. SHT. DWG. NO.

DATE | PROJECT Shipwars | 200 S 33rd Street Detkin Lab APPROVALS Philadelphia PA 19104

ENG: SP, PS

DSN: SP, PS

PROJECT REVISION: | DOCUMENT REVISION: | DESIGN ITEM:

CHK: SP, PS

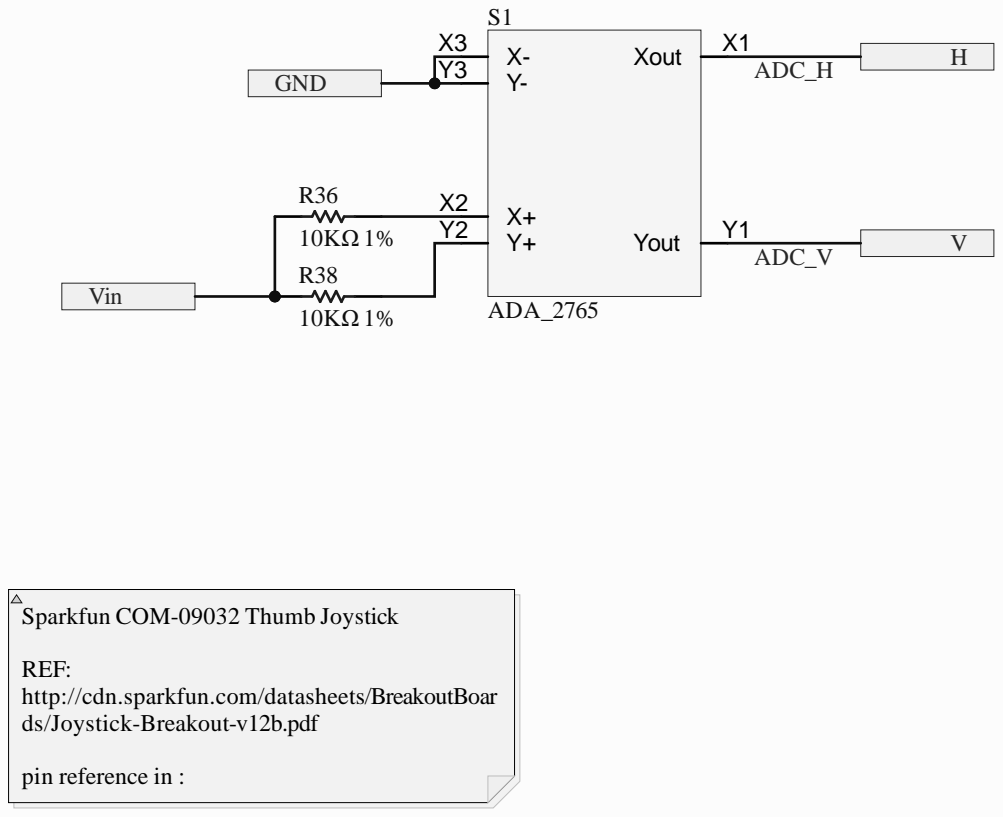
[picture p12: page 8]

Sparkfun COM-09032 Thumb Joystick

REF:
http://cdn.sparkfun.com/datasheets/BreakoutBoar
ds/Joystick-Breakout-v12b.pdf

REV. SHT. DWG. NO.

DATE | PROJECT Shipwars | 200 S 33rd Street Detkin Lab APPROVALS Philadelphia PA 19104

ENG: SP, PS

DSN: SP, PS

PROJECT REVISION: | DOCUMENT REVISION: | DESIGN ITEM:

CHK: SP, PS

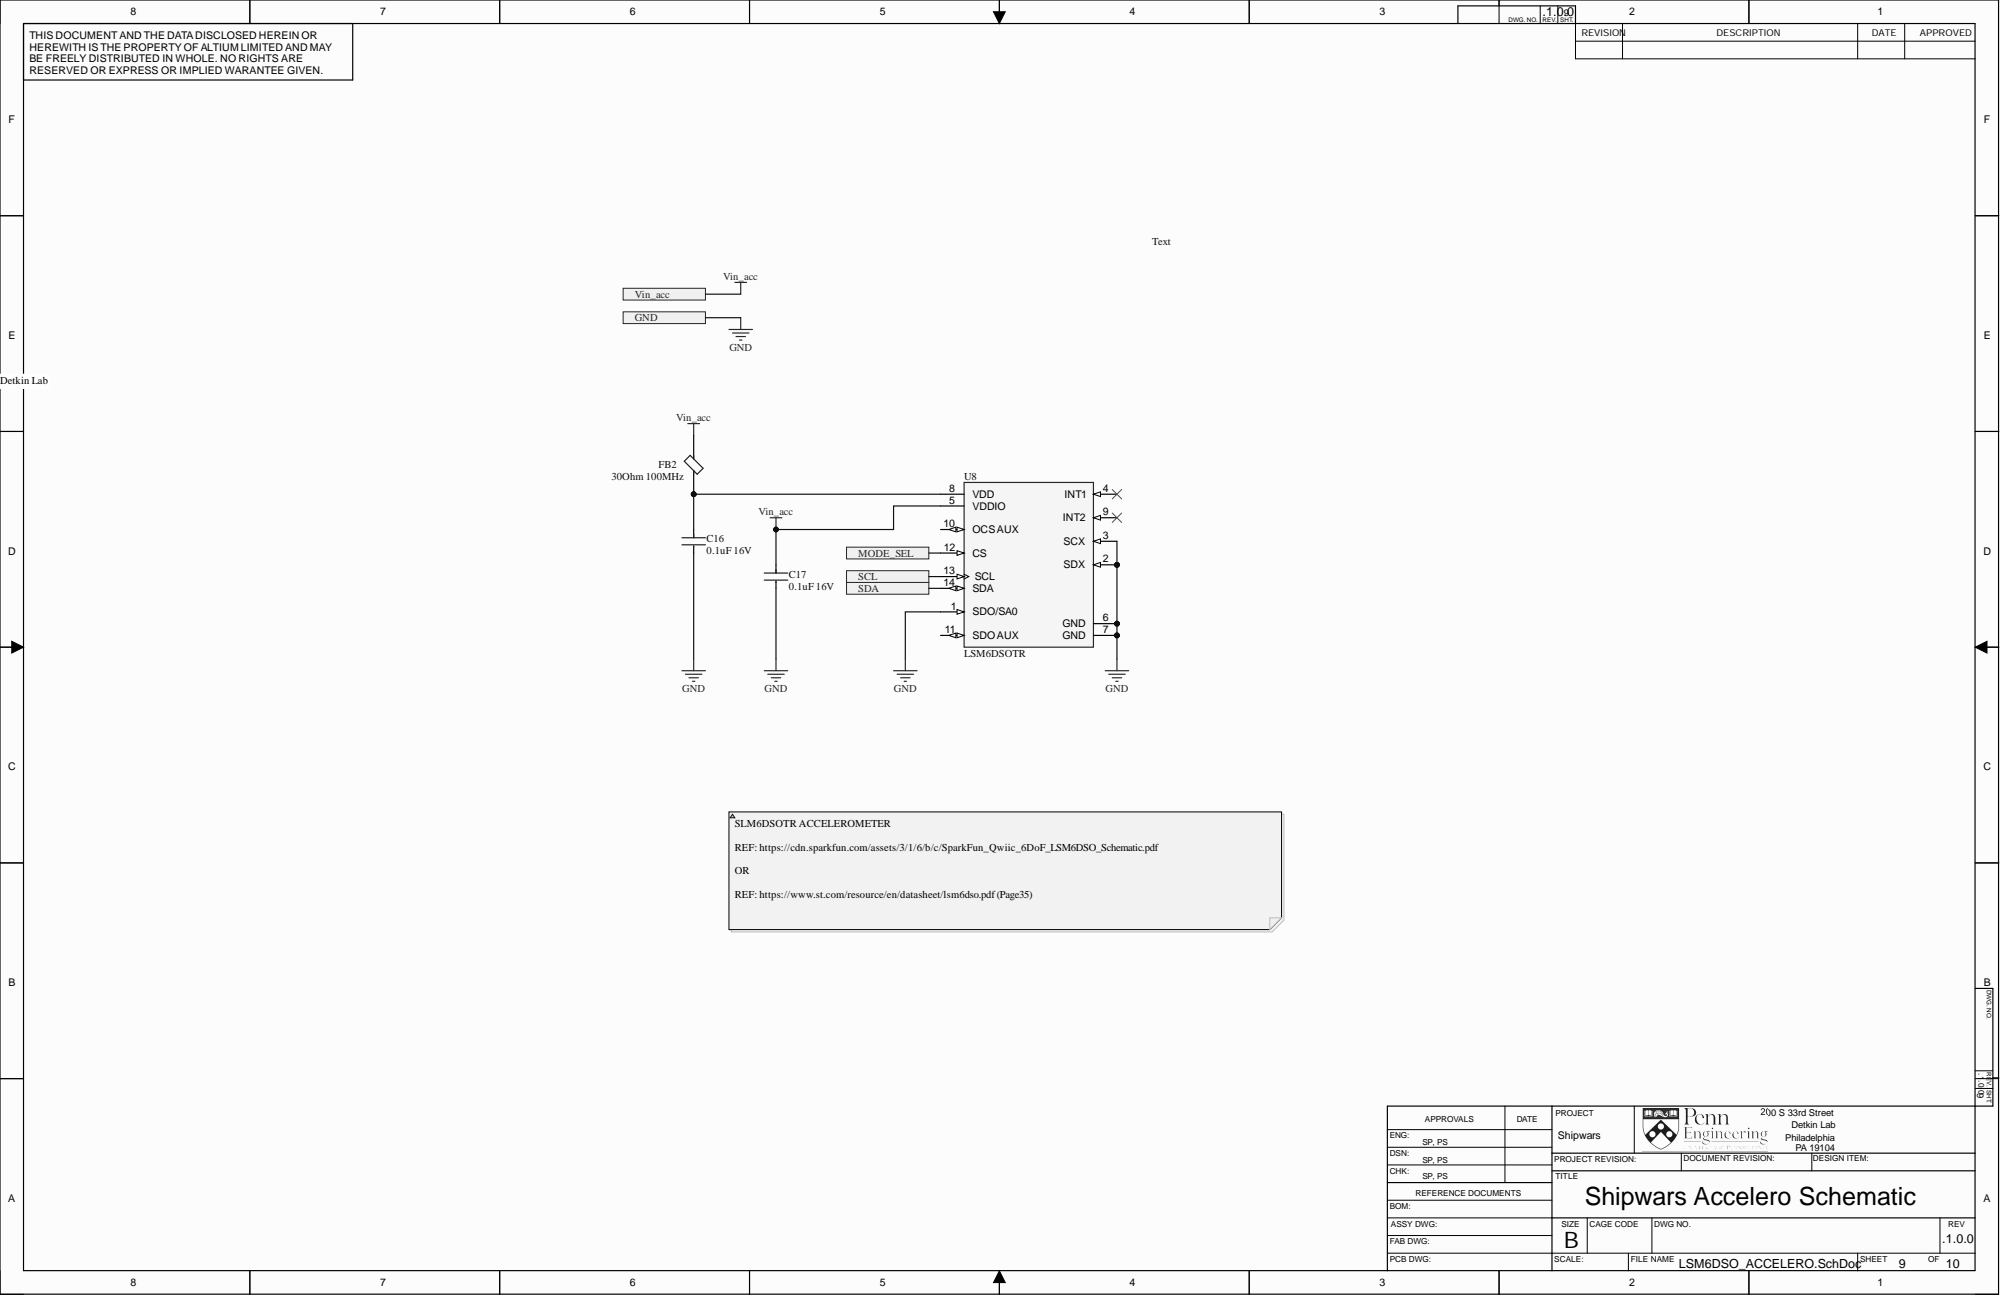
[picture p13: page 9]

SDO AUX 11

REF: https://cdn.sparkfun.com/assets/3/1/6/b/c/SparkFun_Qwiic_6DoF_LSM6DSO_Schematic.pdf

REF: https://www.st.com/resource/en/datasheet/lsm6dso.pdf (Page35)

REV. SHT. DWG. NO.

DATE | PROJECT Shipwars | 200 S 33rd Street Detkin Lab APPROVALS Philadelphia PA 19104

ENG: SP, PS

DSN: SP, PS

PROJECT REVISION: | DOCUMENT REVISION: | DESIGN ITEM:

CHK: SP, PS

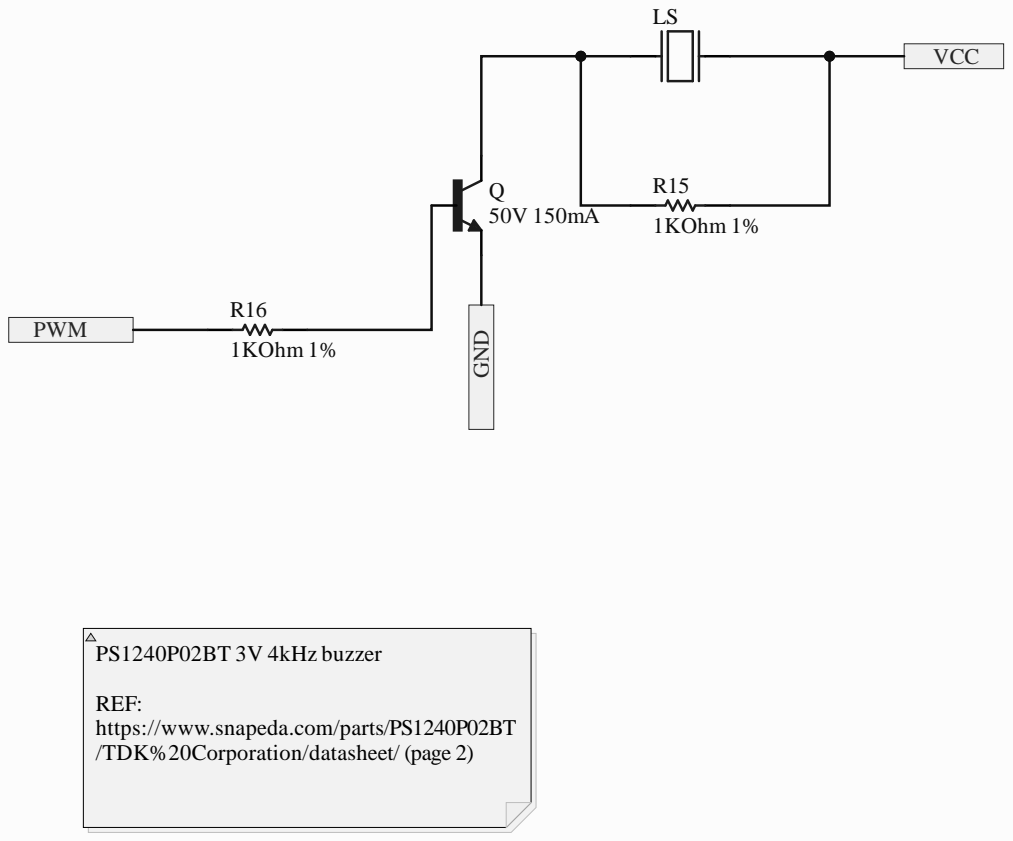
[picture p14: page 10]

DWG . N O . | R E . | S T.

T IS DOC U MEN T AN D T HE D ATA D ISCLOSED HEREI N OR HEREW I T IS T HE PROPER TY OF ALT I U M LI M I TED AN D M AY BE F REELY D IST R IBU TED I N W HOLE. NO R IGH TS ARE RESERVED OR EXPRESS OR I MPLIED WARAN TEE GIVEN . | | REVISI O | N DESC R IPT I O N | DAT E | APPR OVED

REV. SHT. DWG. NO.

DATE | PRO JECT Shipw a rs | 2 0 0 S 3 3rd Stre e t b APPROVALS D e tki n L a Ph i l a d e l p h i a PA 1 9 1 0 4

ENG : SP, PS

DSN: SP, PS

PRO JECT REVISION: | DOCUMENT REVISION: | DESIGN ITEM :

CHK: SP, PS

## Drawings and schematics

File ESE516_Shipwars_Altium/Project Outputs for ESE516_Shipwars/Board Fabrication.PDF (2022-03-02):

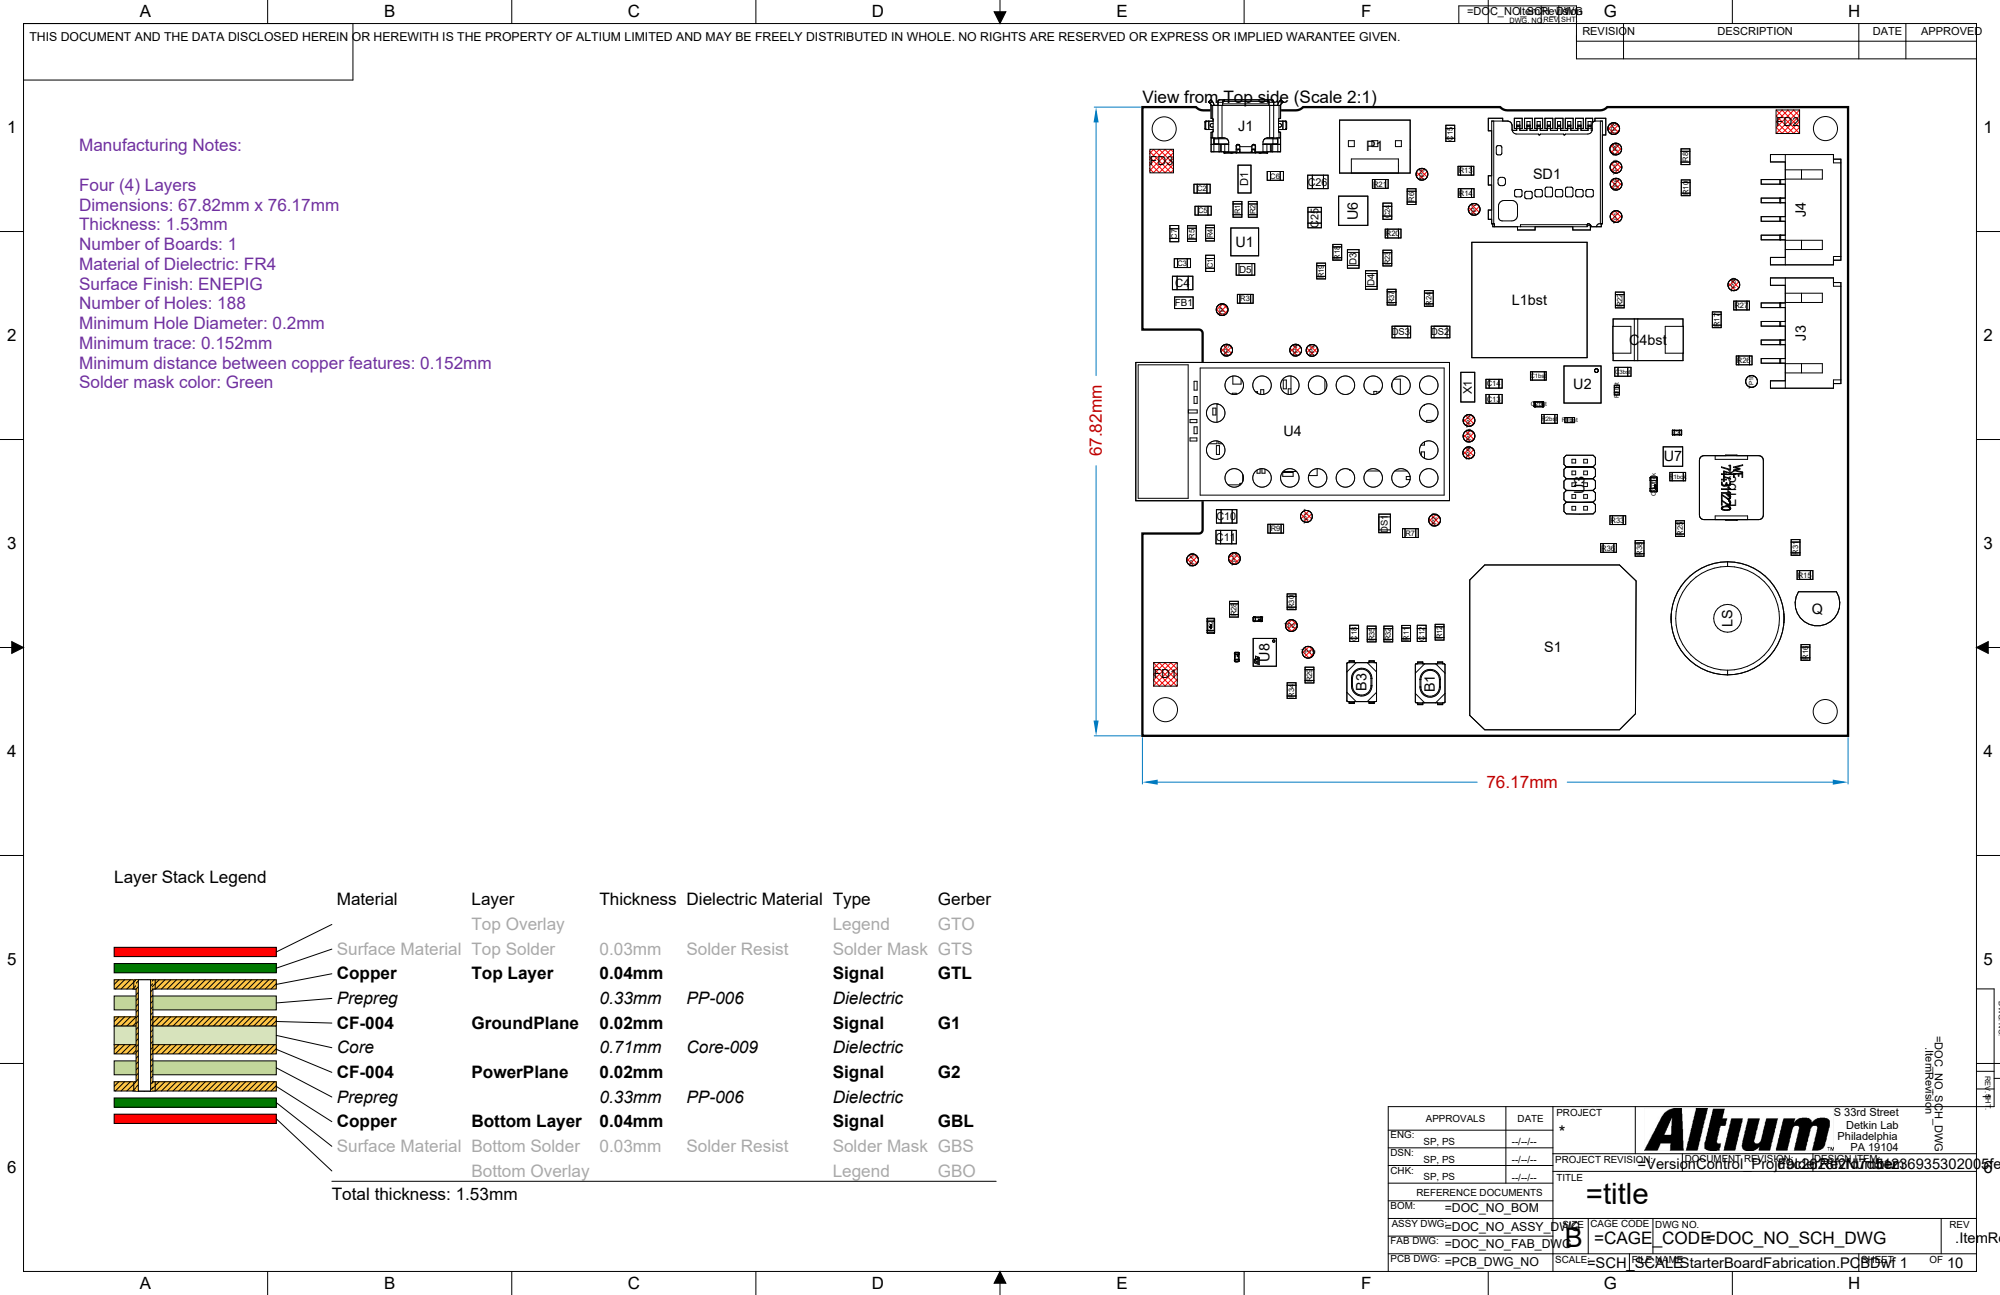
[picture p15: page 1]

DWG. NO.REV.SHT.

THIS DOCUMENT AND THE DATA DISCLOSED HEREIN OR HEREWITH IS THE PROPERTY OF ALTIUM LIMITED AND MAY BE FREELY DISTRIBUTED IN WHOLE. NO RIGHTS ARE RESERVED OR EXPRESS OR IMPLIED WARANTEE GIVEN.

View from Top side (Scale 2:1)

Minimum Hole Diameter: 0.2mm
Minimum trace: 0.152mm
Minimum distance between copper features: 0.152mm
Solder mask color: Green

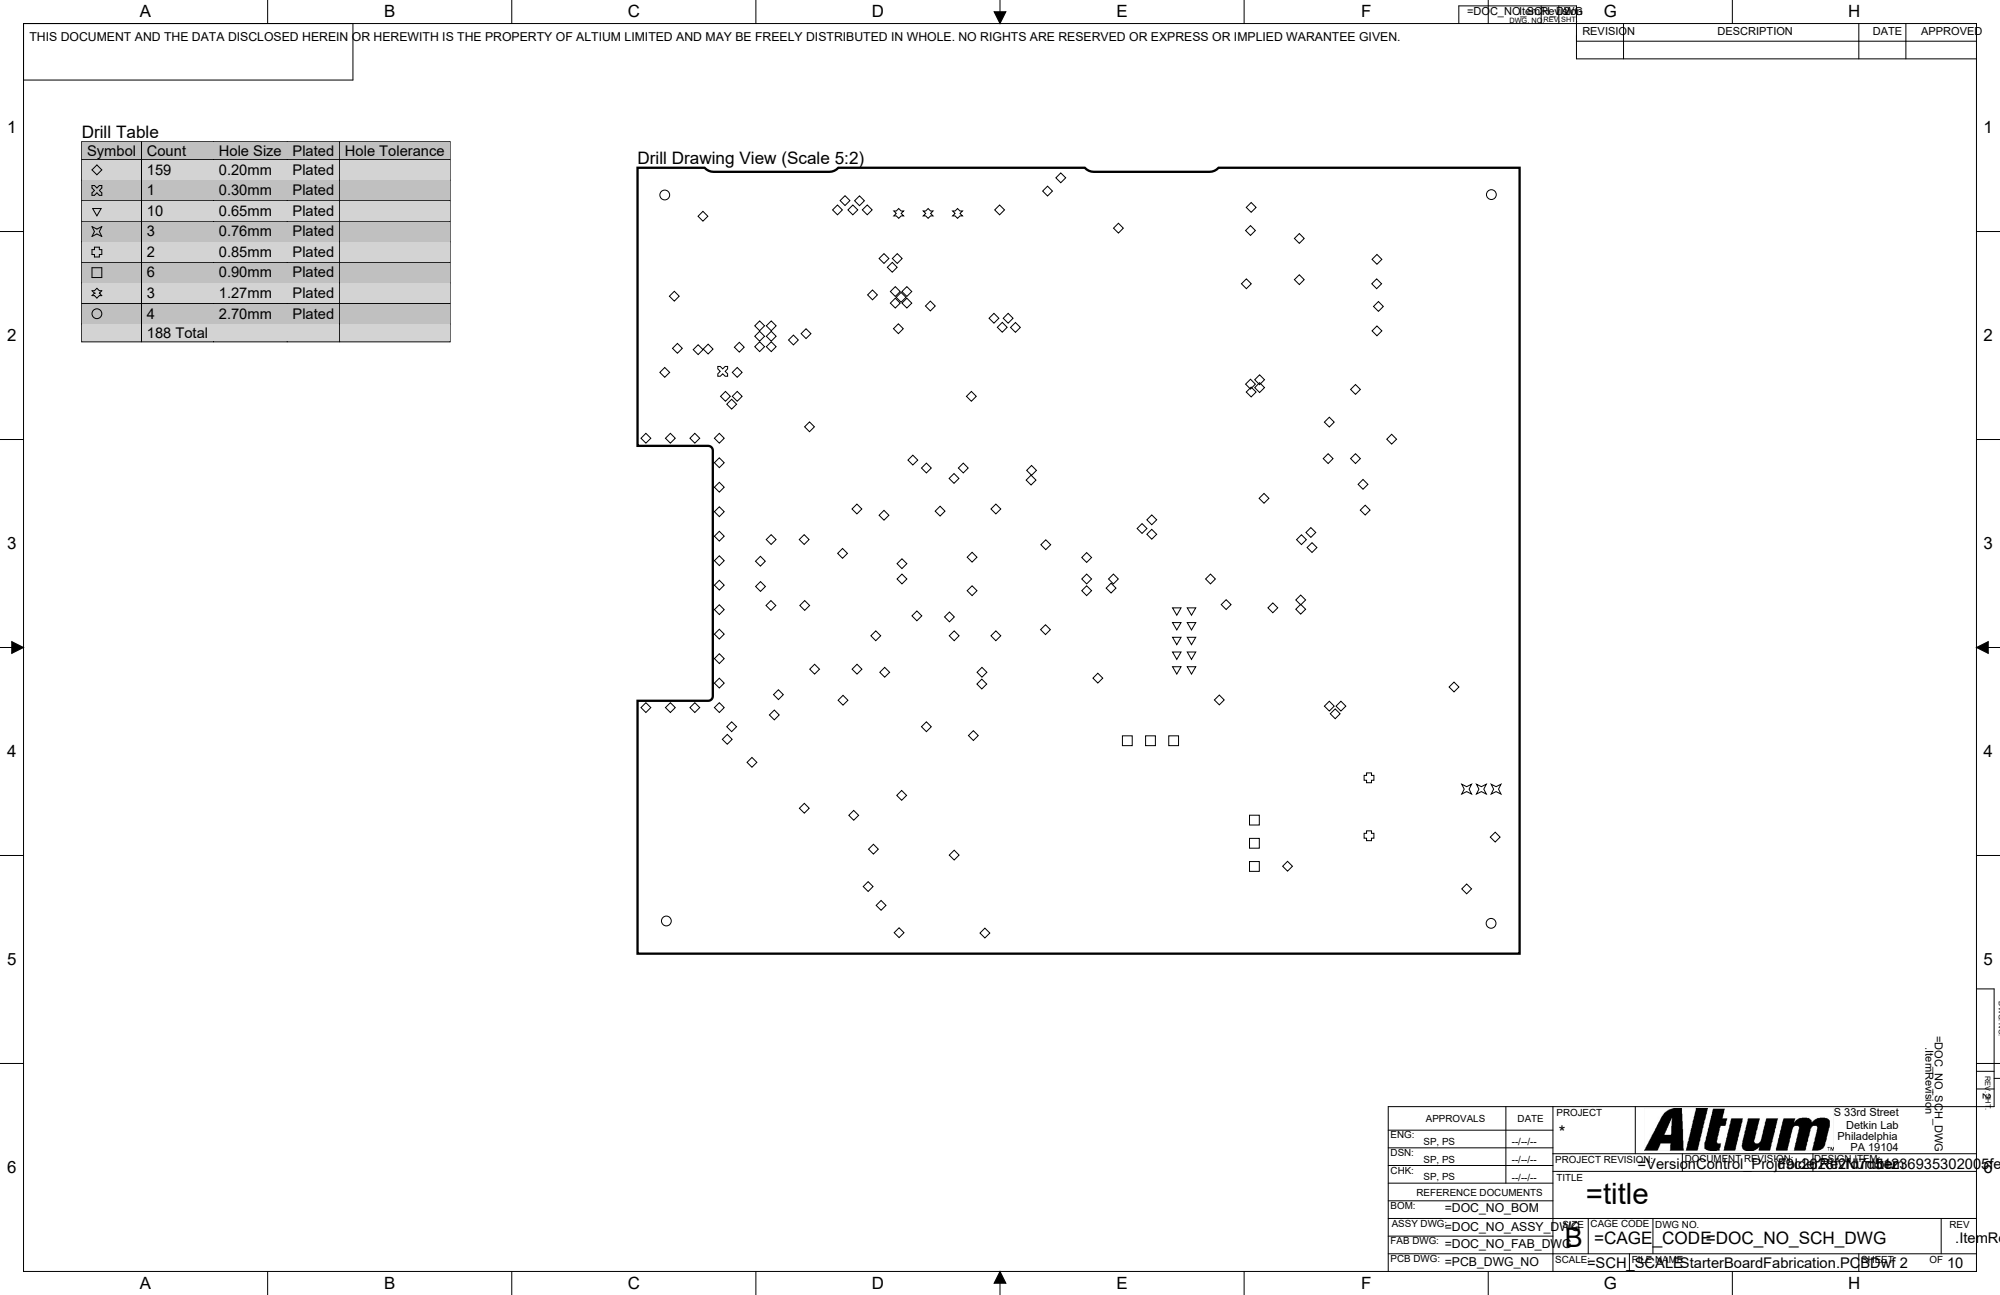
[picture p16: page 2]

Symbol | Count | Hole Size | Plated | Hole Tolerance

Drill Drawing View (Scale 5:2)

159 | 0.20mm | Plated
1 | 0.30mm | Plated
10 | 0.65mm | Plated
3 | 0.76mm | Plated
2 | 0.85mm | Plated
6 | 0.90mm | Plated
3 | 1.27mm | Plated
4 | 2.70mm | Plated
188 Total

APPROVALS | DATE

ENG: SP, PS | --/--/--
DSN: SP, PS | --/--/--
CHK: SP, PS | --/--/--

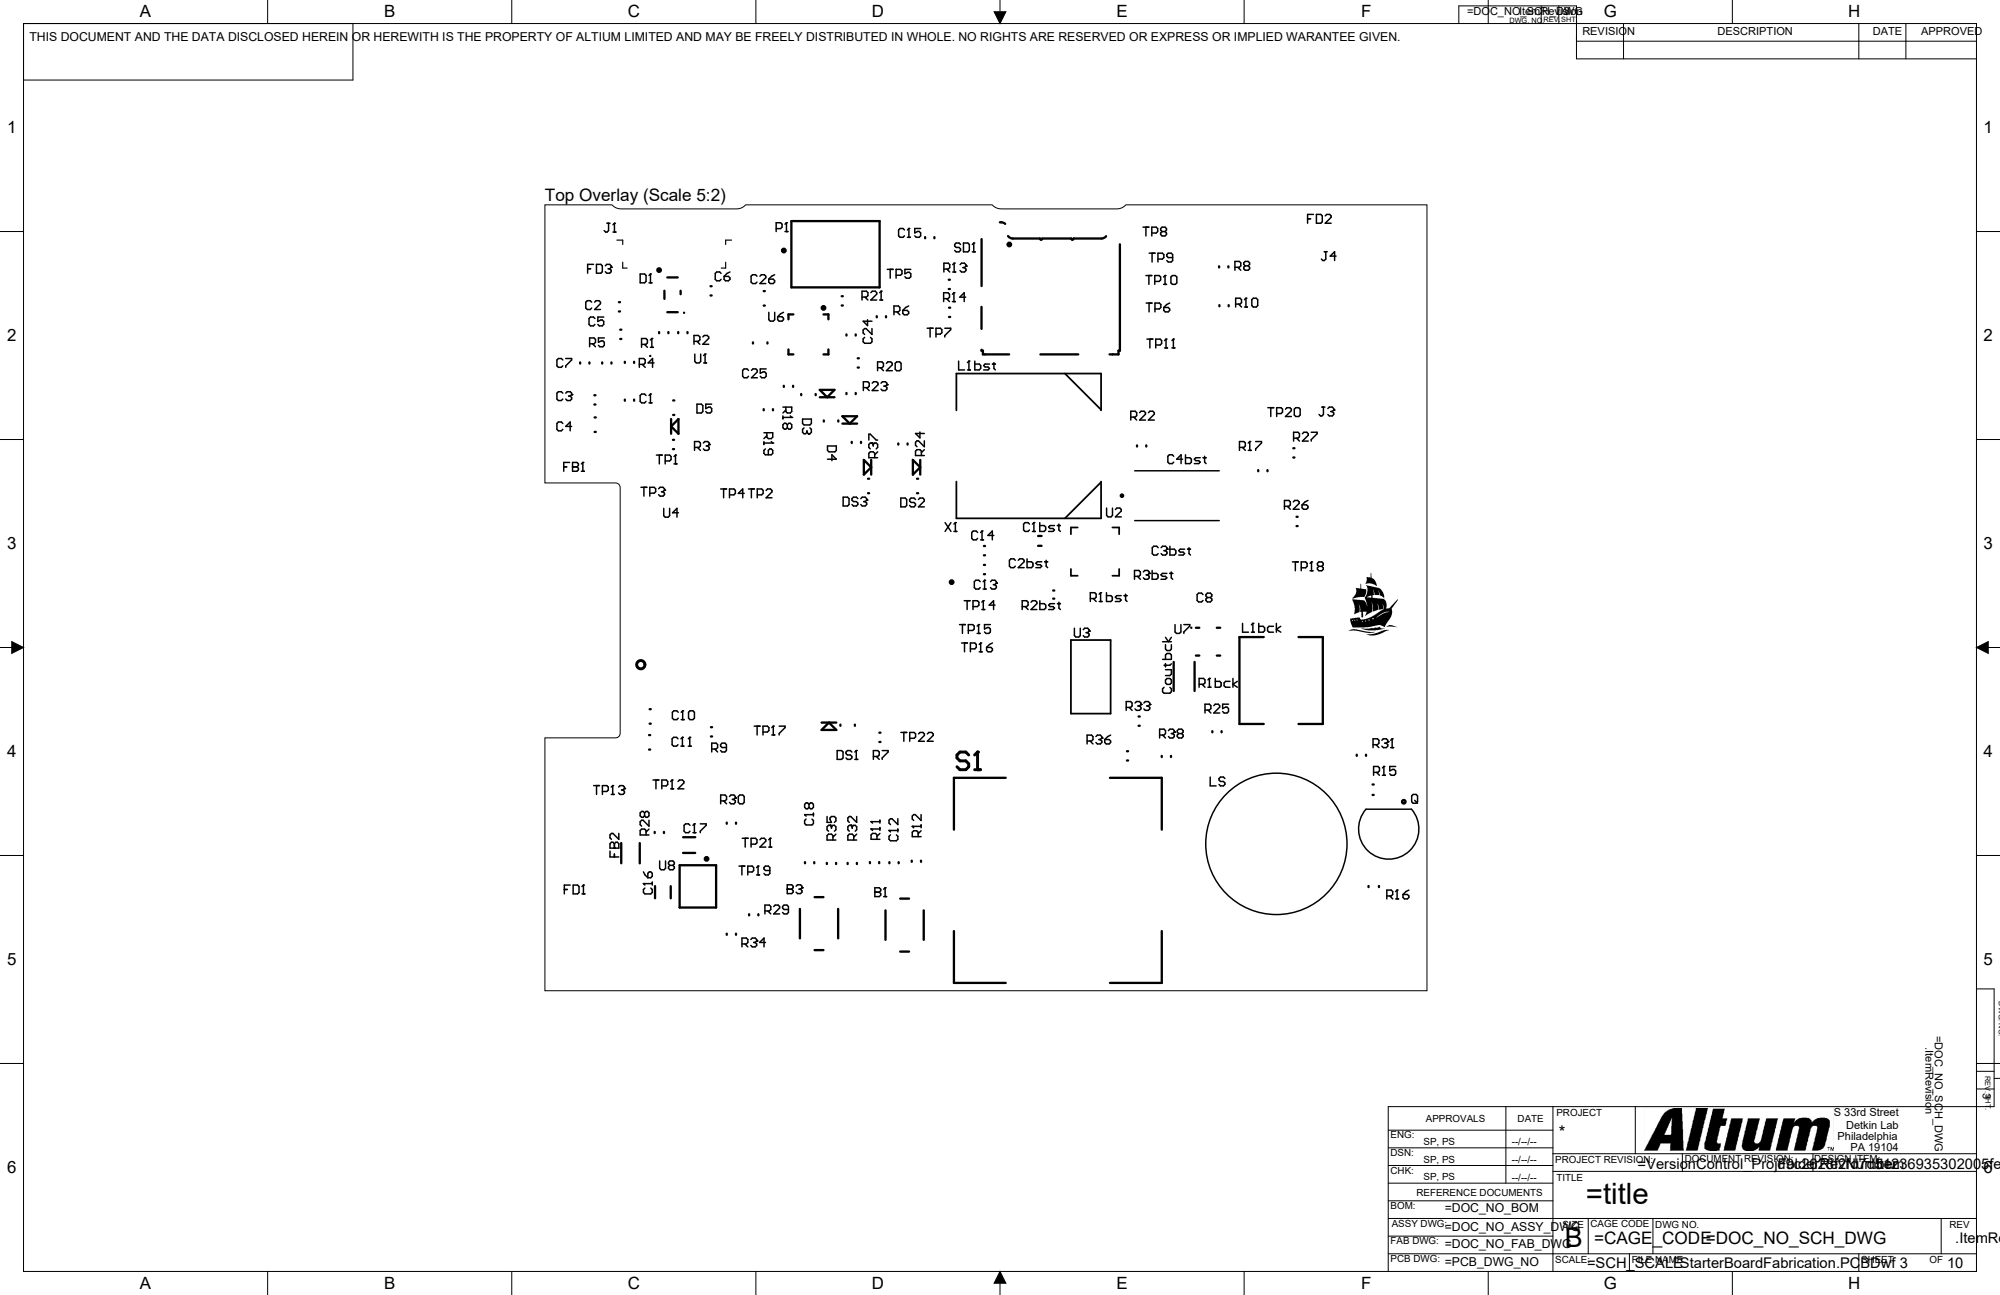
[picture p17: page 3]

APPROVALS | DATE

ENG: SP, PS | --/--/--
DSN: SP, PS | --/--/--
CHK: SP, PS | --/--/--

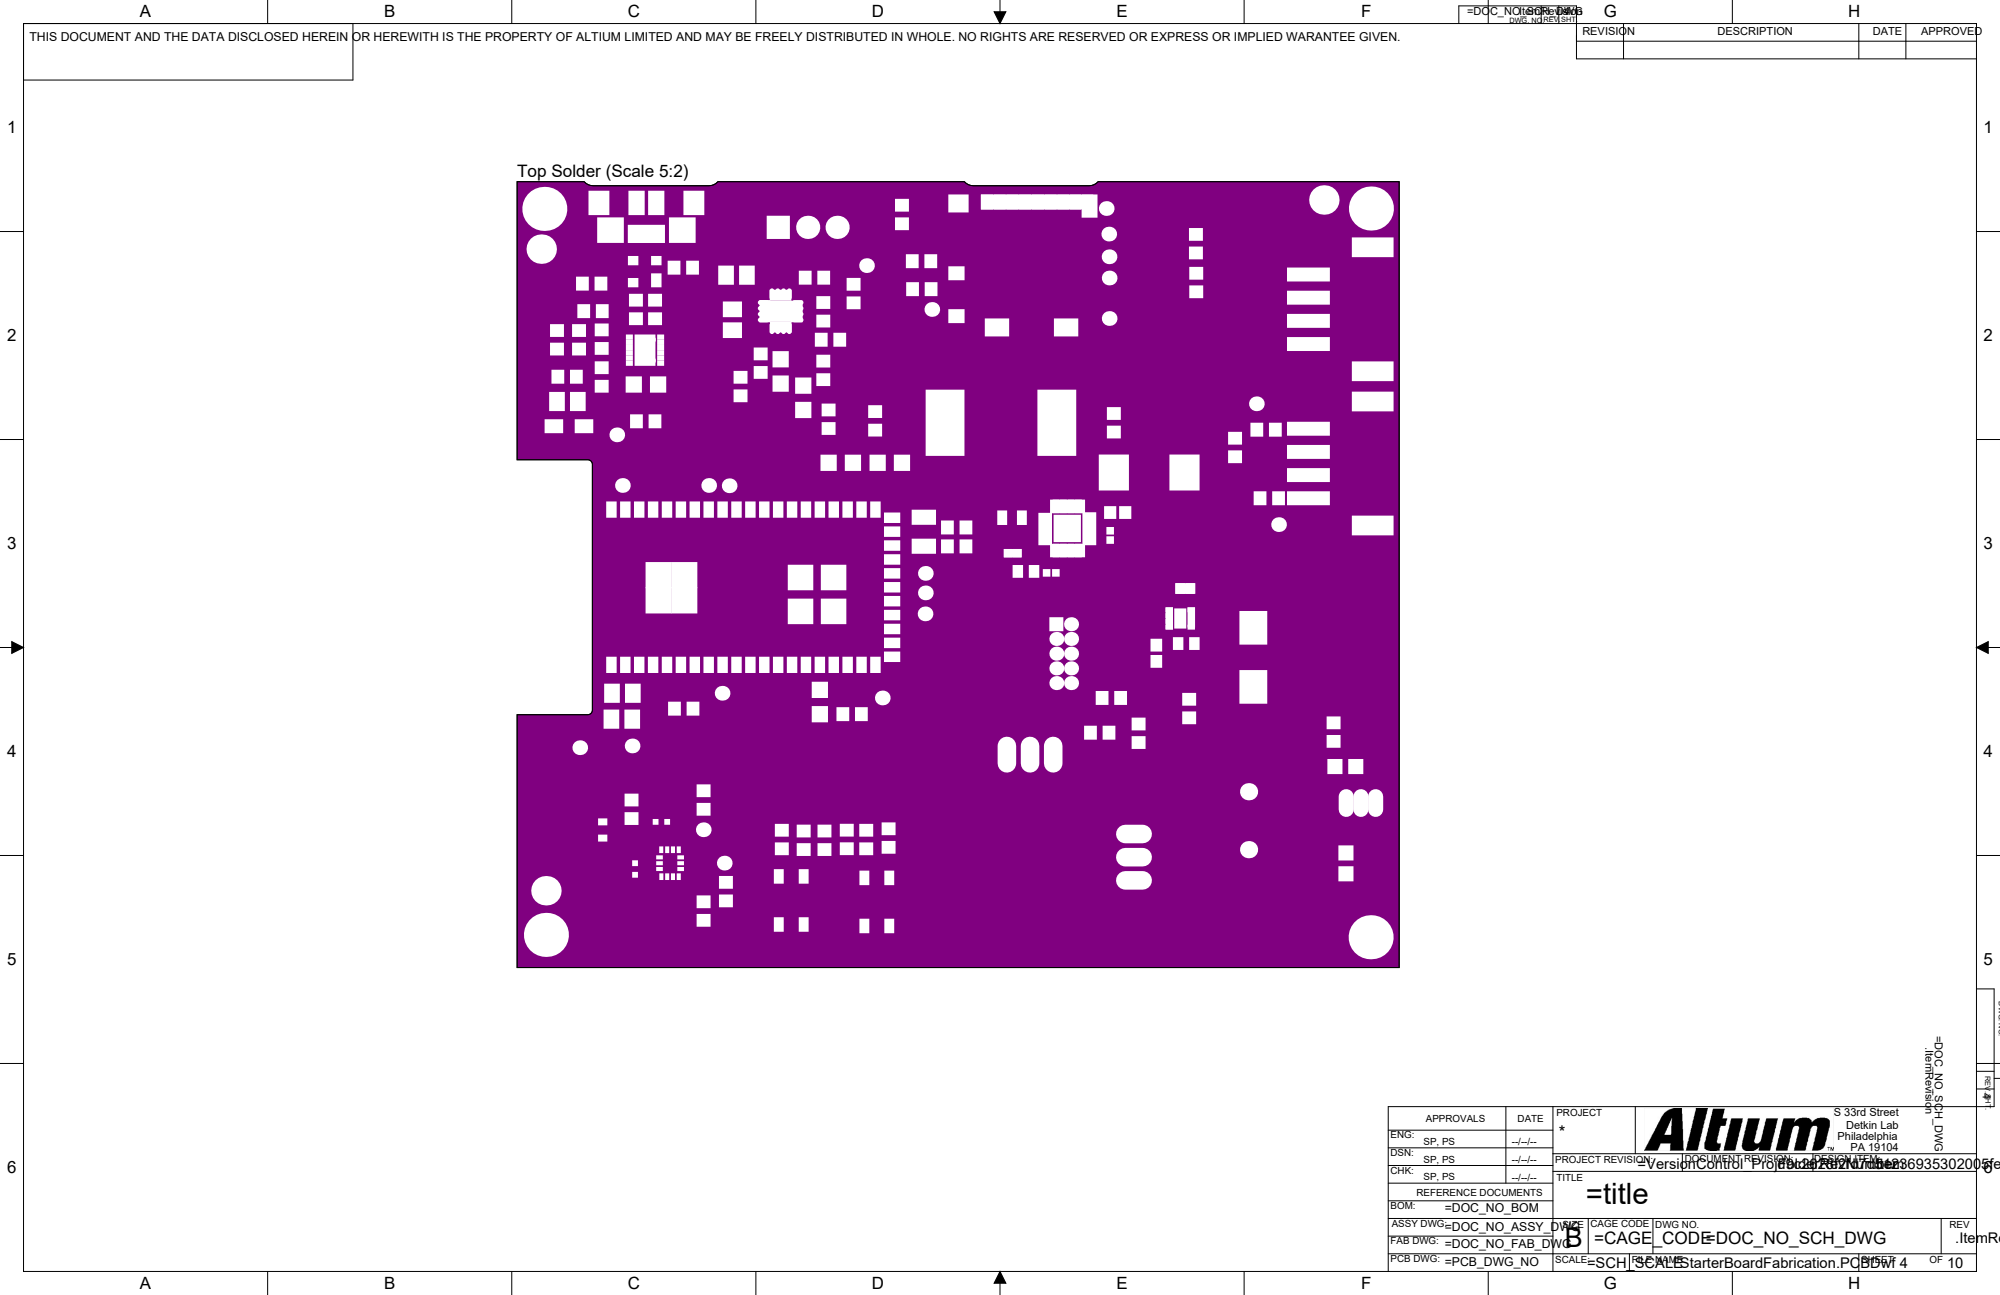
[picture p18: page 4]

APPROVALS | DATE

ENG: SP, PS | --/--/--
DSN: SP, PS | --/--/--
CHK: SP, PS | --/--/--

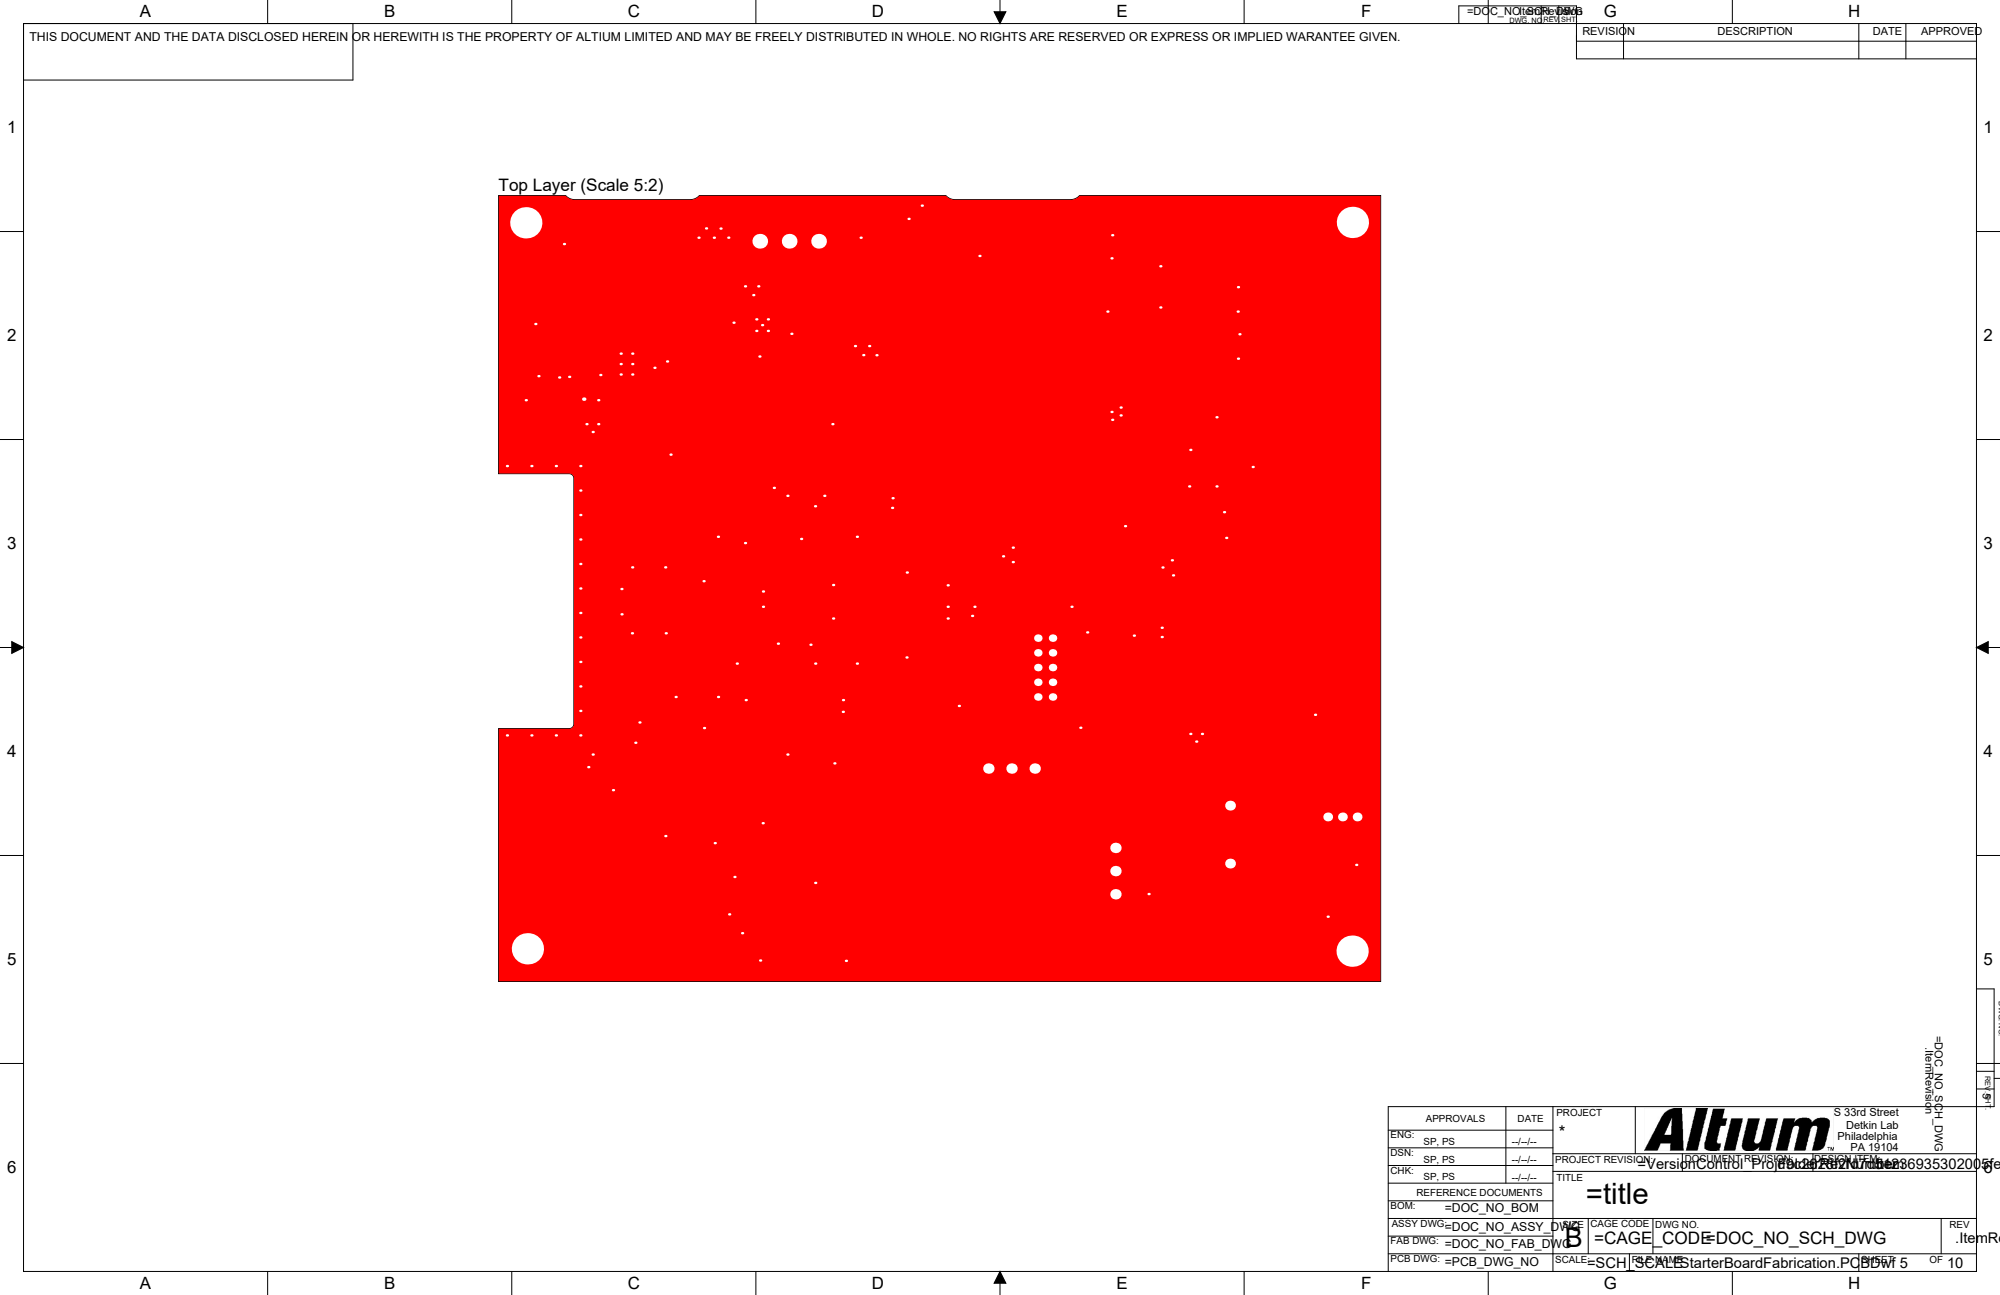
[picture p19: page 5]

APPROVALS | DATE

ENG: SP, PS | --/--/--
DSN: SP, PS | --/--/--
CHK: SP, PS | --/--/--

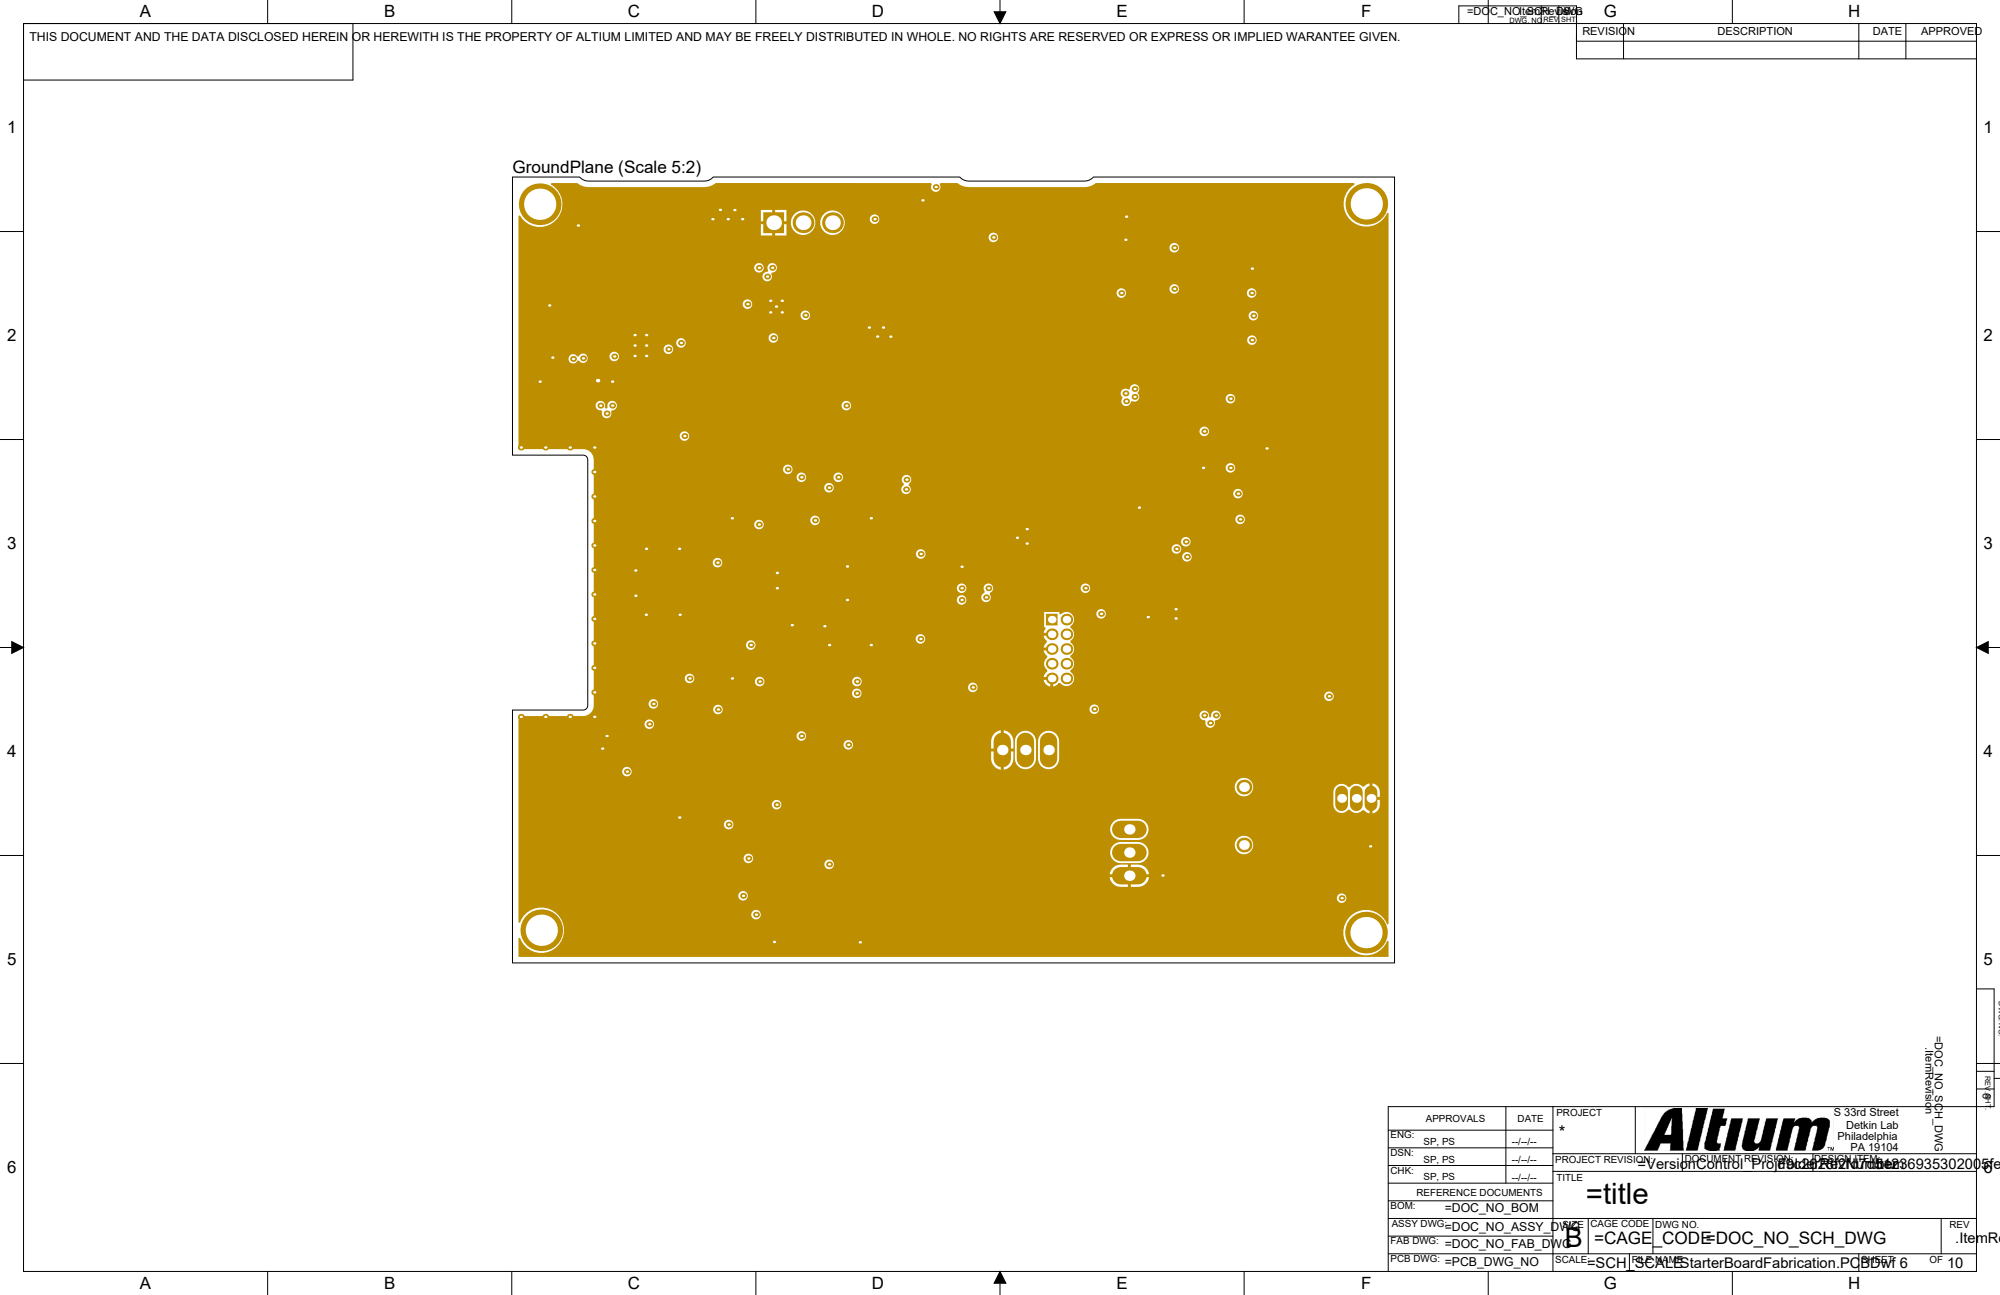
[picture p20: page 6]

APPROVALS | DATE

ENG: SP, PS | --/--/--
DSN: SP, PS | --/--/--
CHK: SP, PS | --/--/--

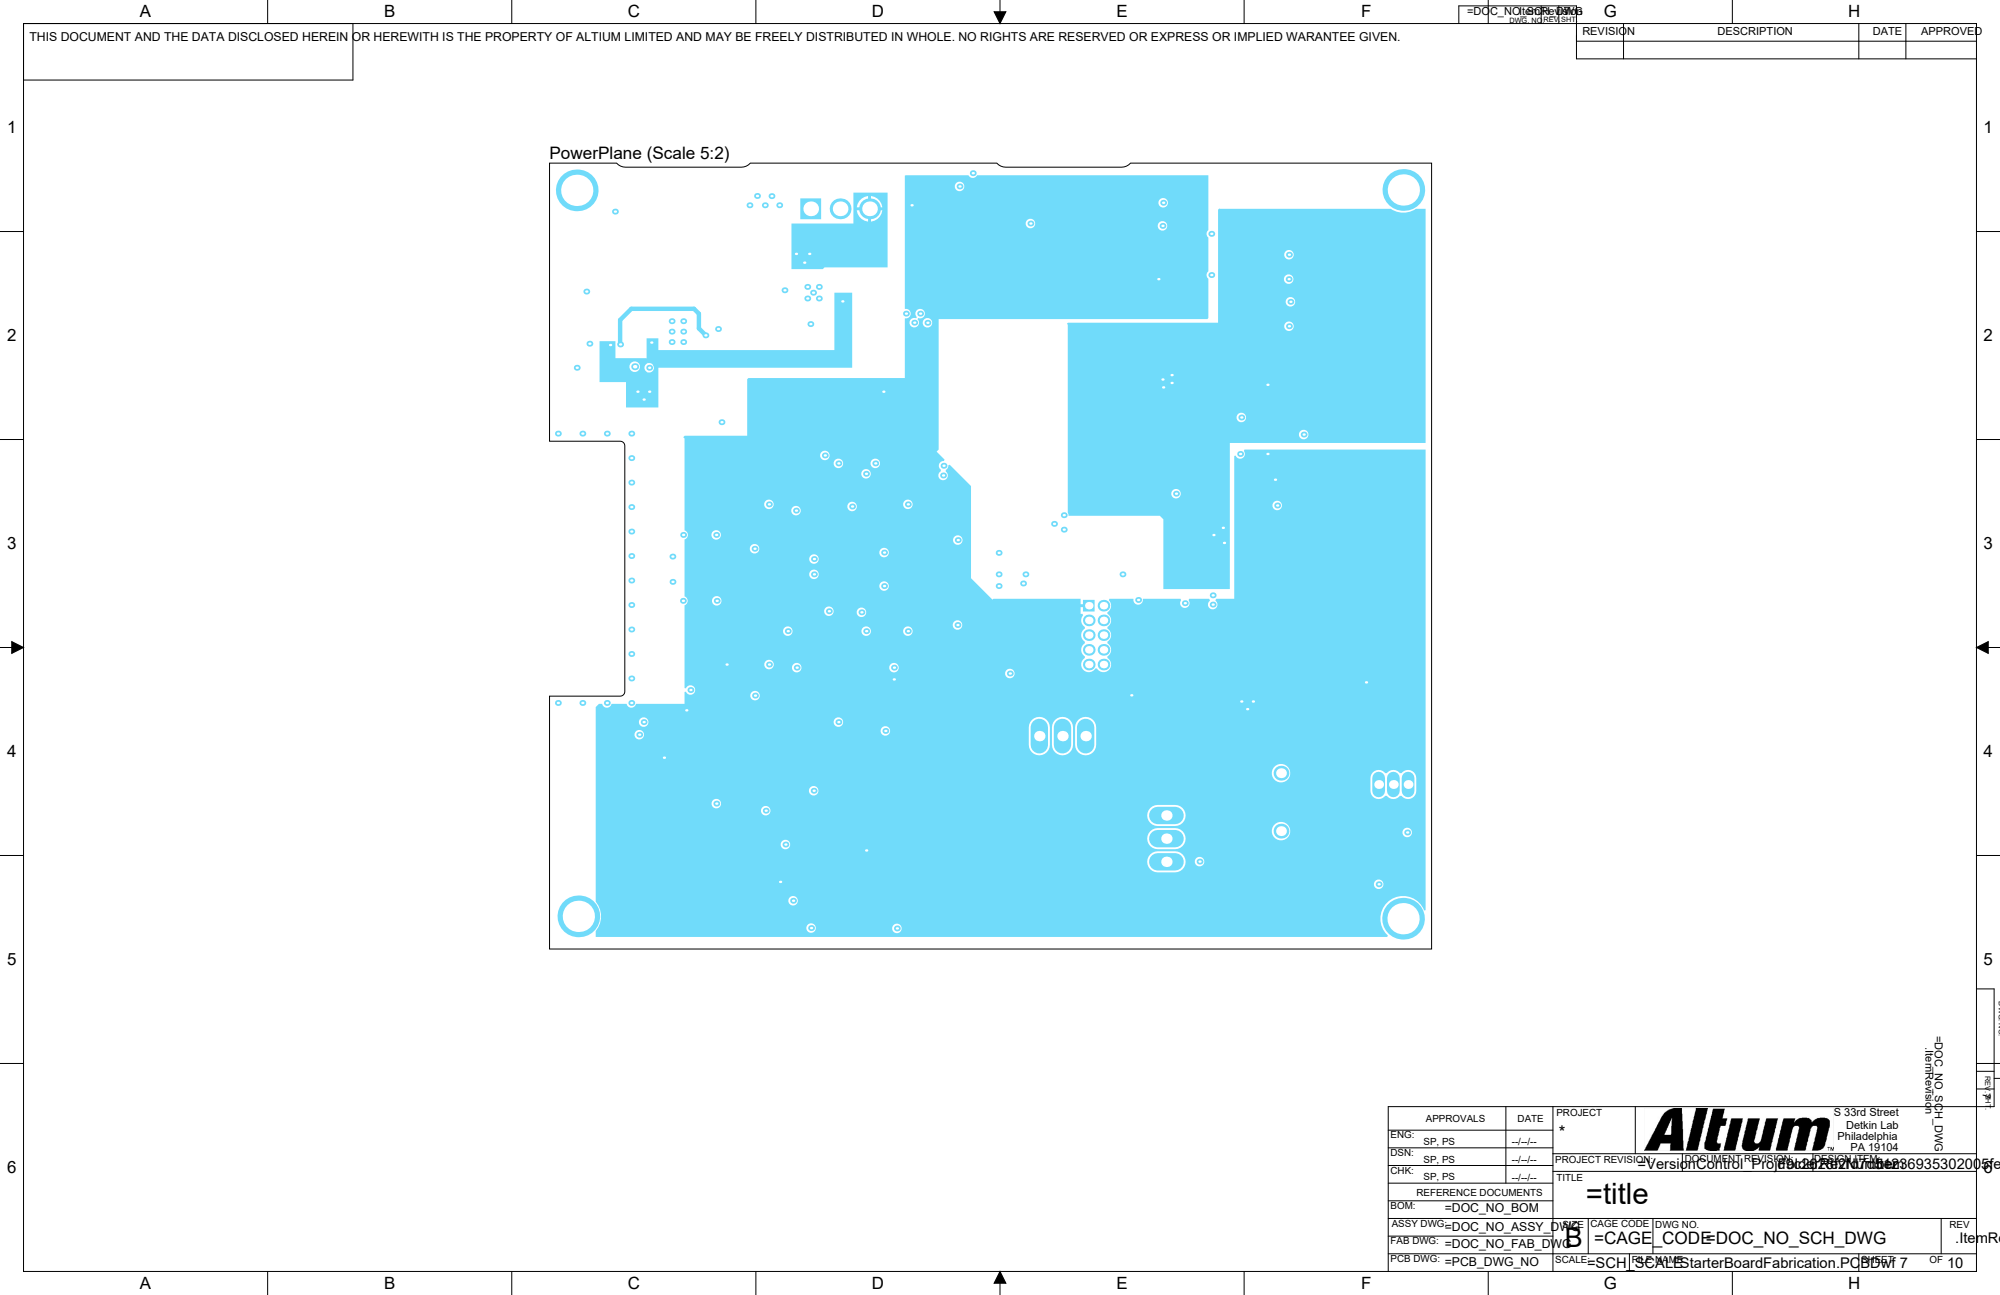
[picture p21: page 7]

APPROVALS | DATE

ENG: SP, PS | --/--/--
DSN: SP, PS | --/--/--
CHK: SP, PS | --/--/--

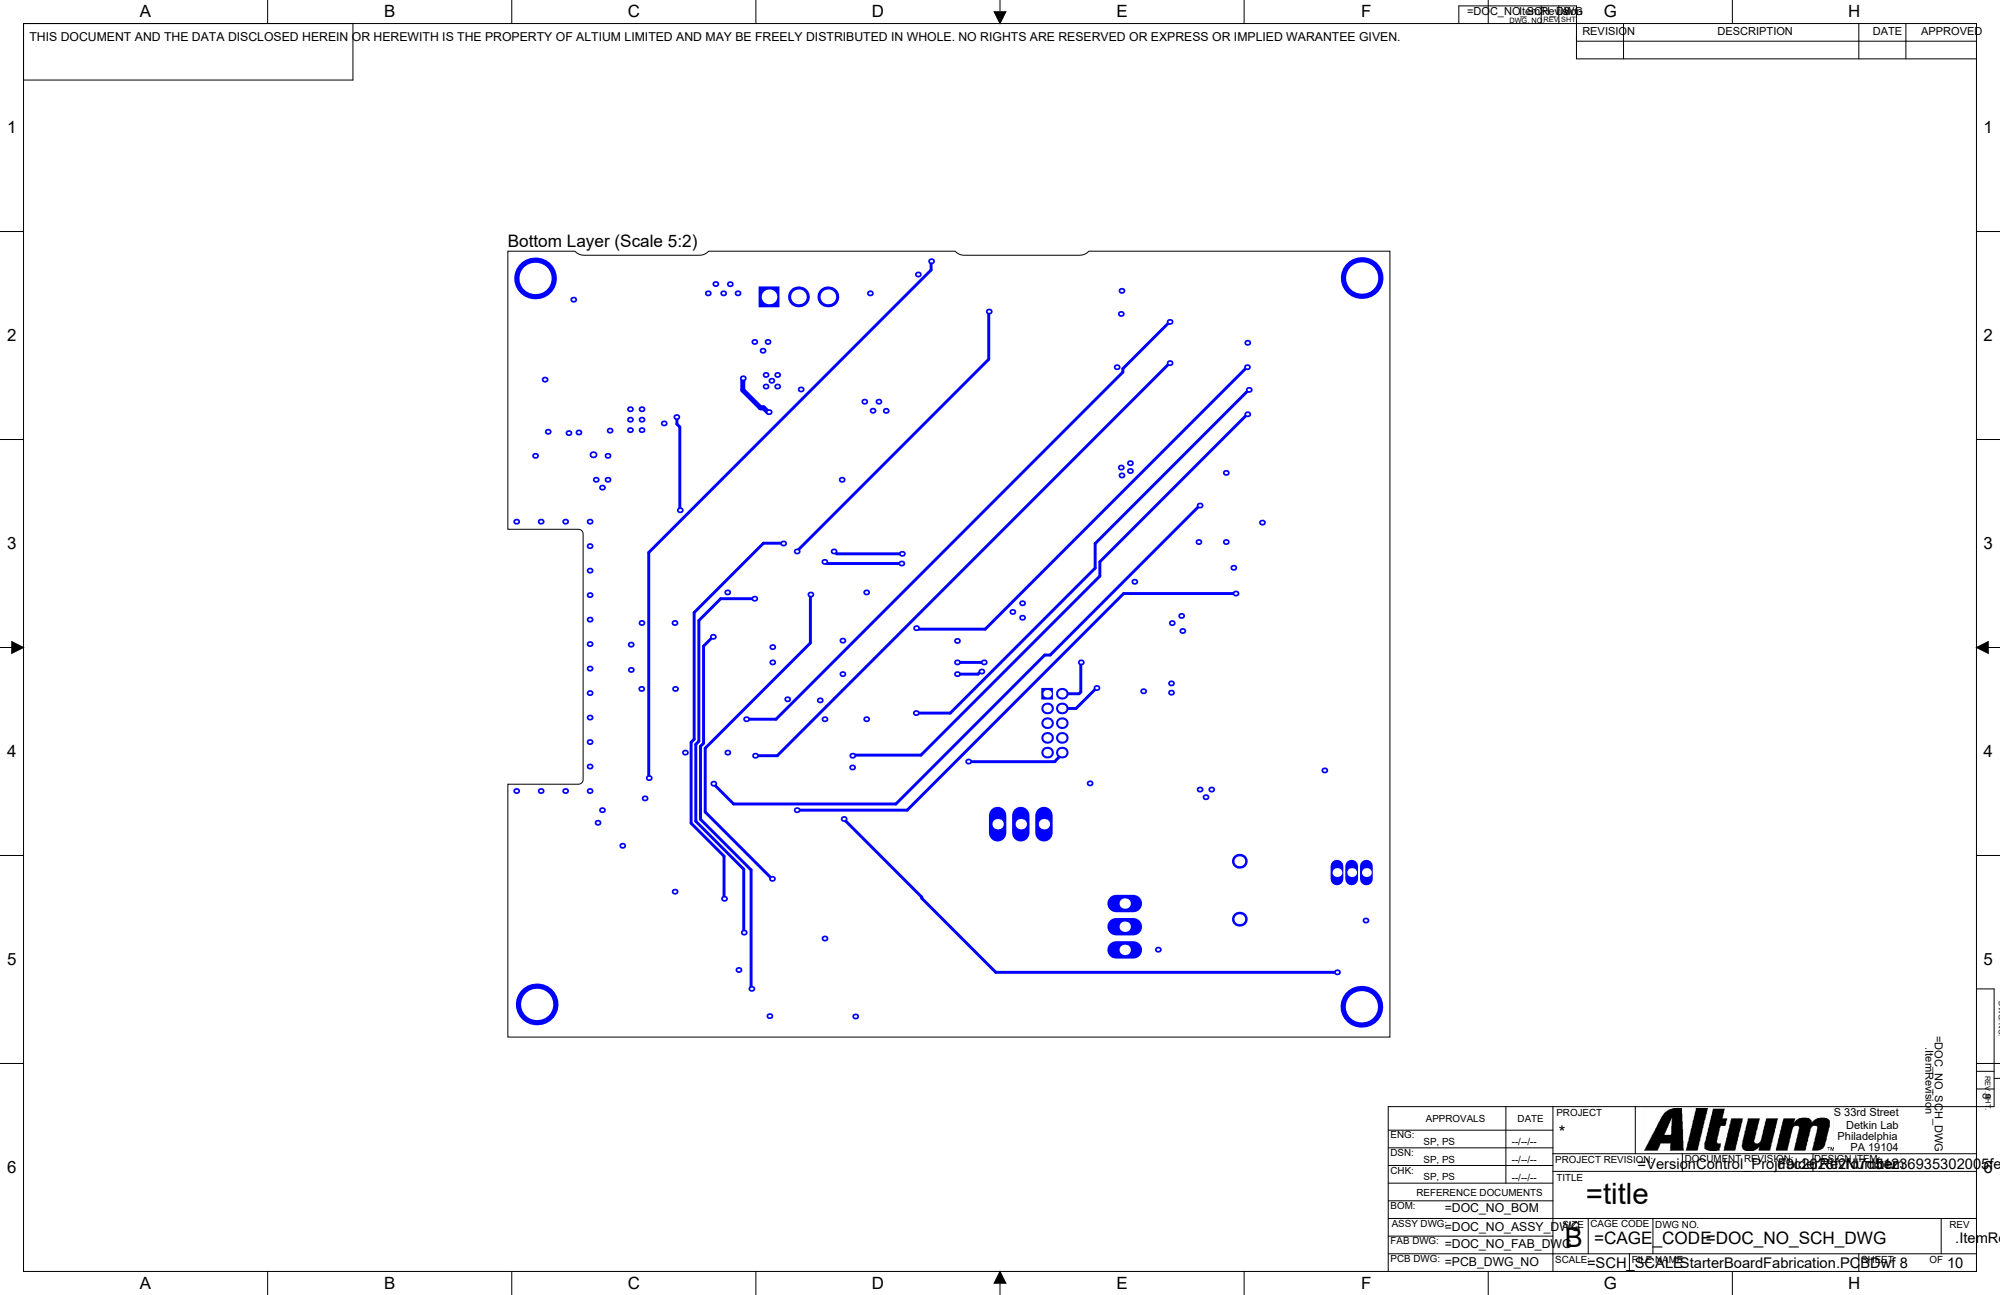
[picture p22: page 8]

APPROVALS | DATE

ENG: SP, PS | --/--/--
DSN: SP, PS | --/--/--
CHK: SP, PS | --/--/--

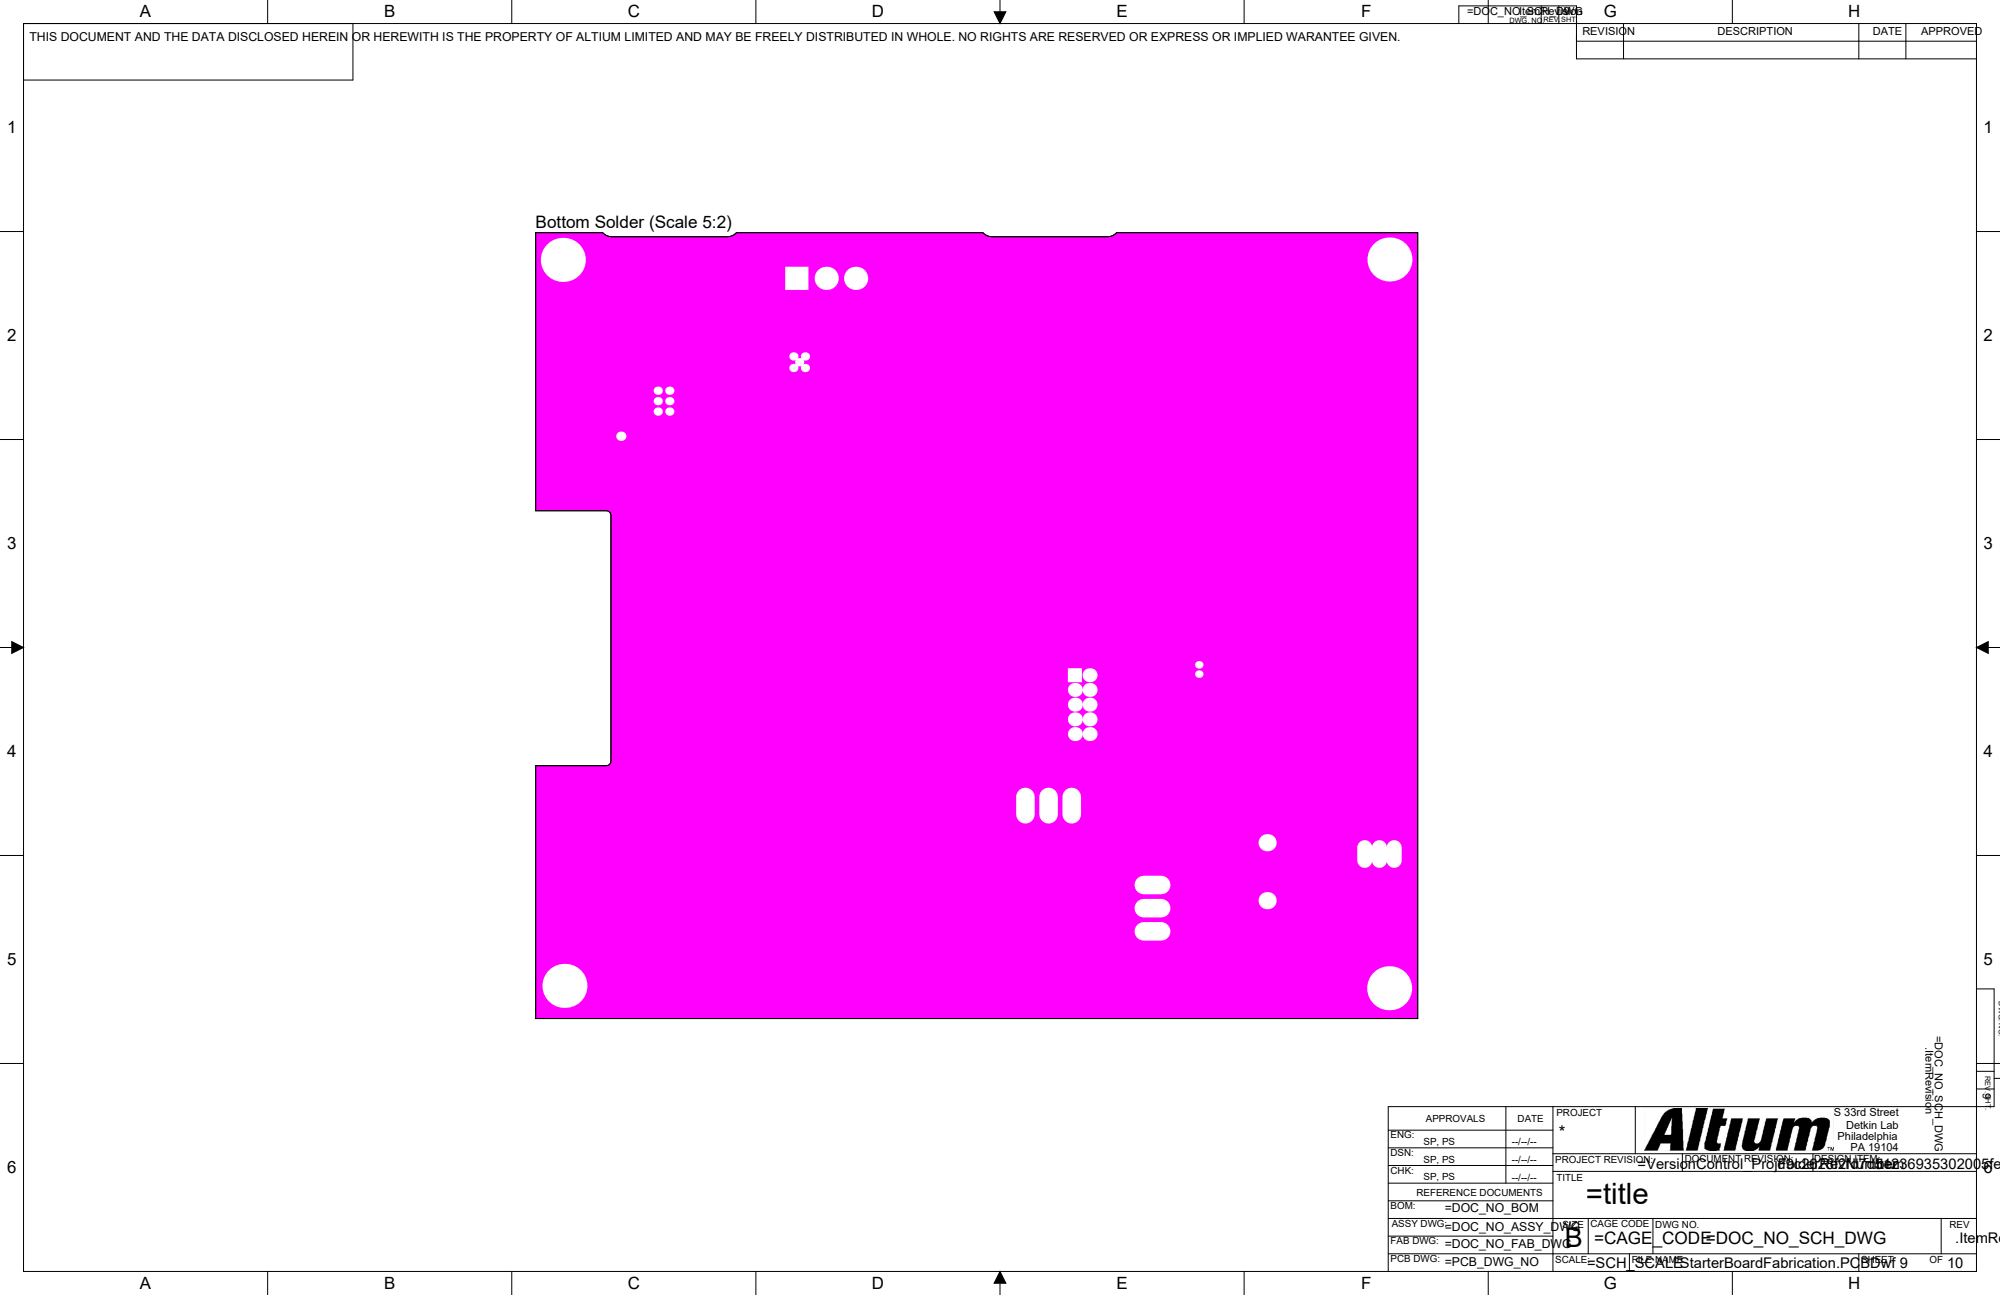
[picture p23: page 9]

APPROVALS | DATE

ENG: SP, PS | --/--/--
DSN: SP, PS | --/--/--
CHK: SP, PS | --/--/--

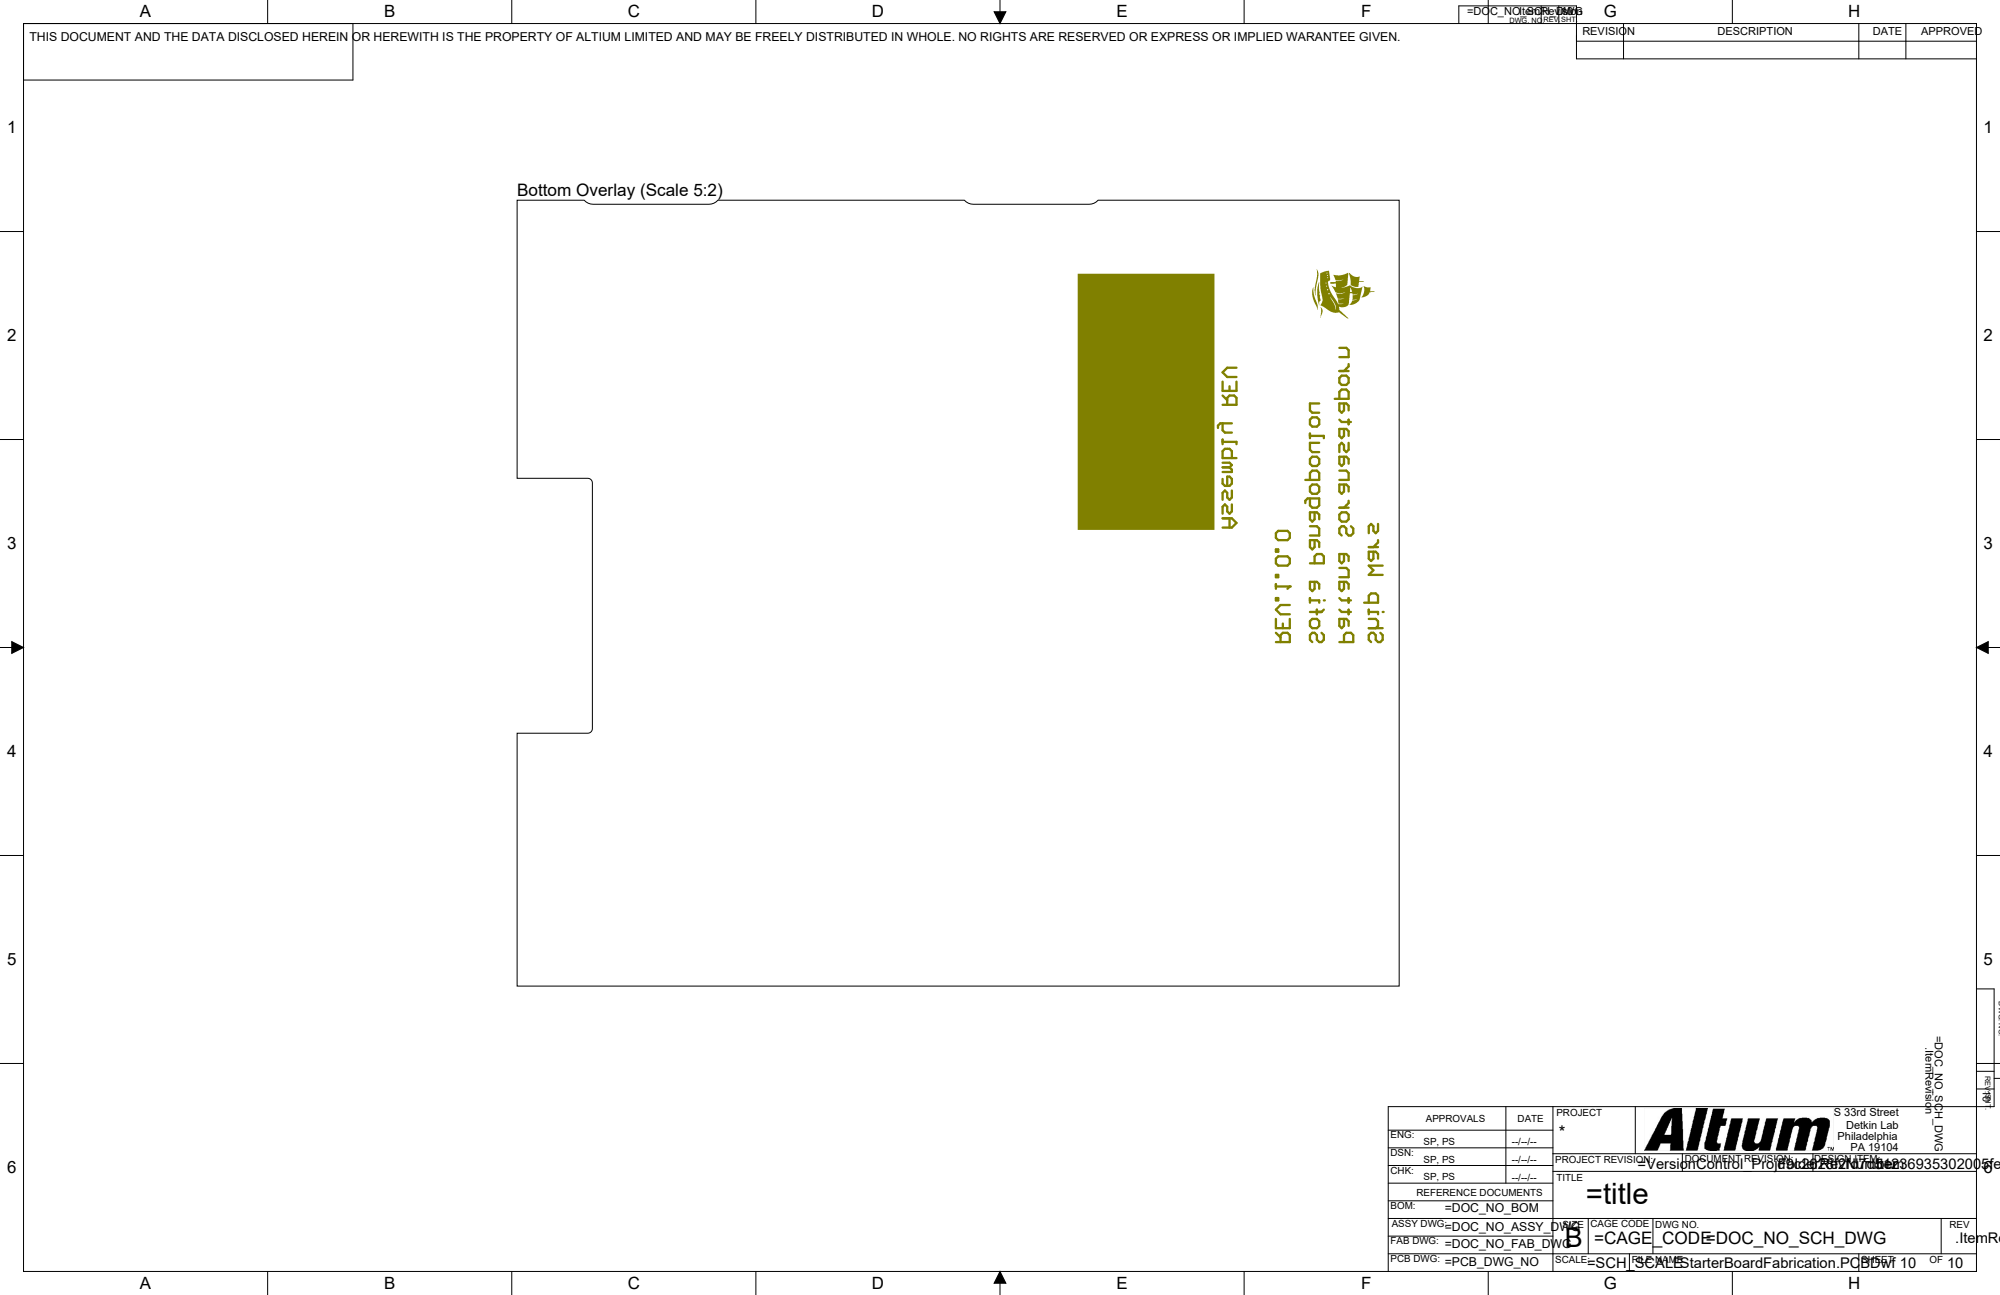
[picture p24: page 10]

APPROVALS | DATE

ENG: SP, PS | --/--/--
DSN: SP, PS | --/--/--
CHK: SP, PS | --/--/--

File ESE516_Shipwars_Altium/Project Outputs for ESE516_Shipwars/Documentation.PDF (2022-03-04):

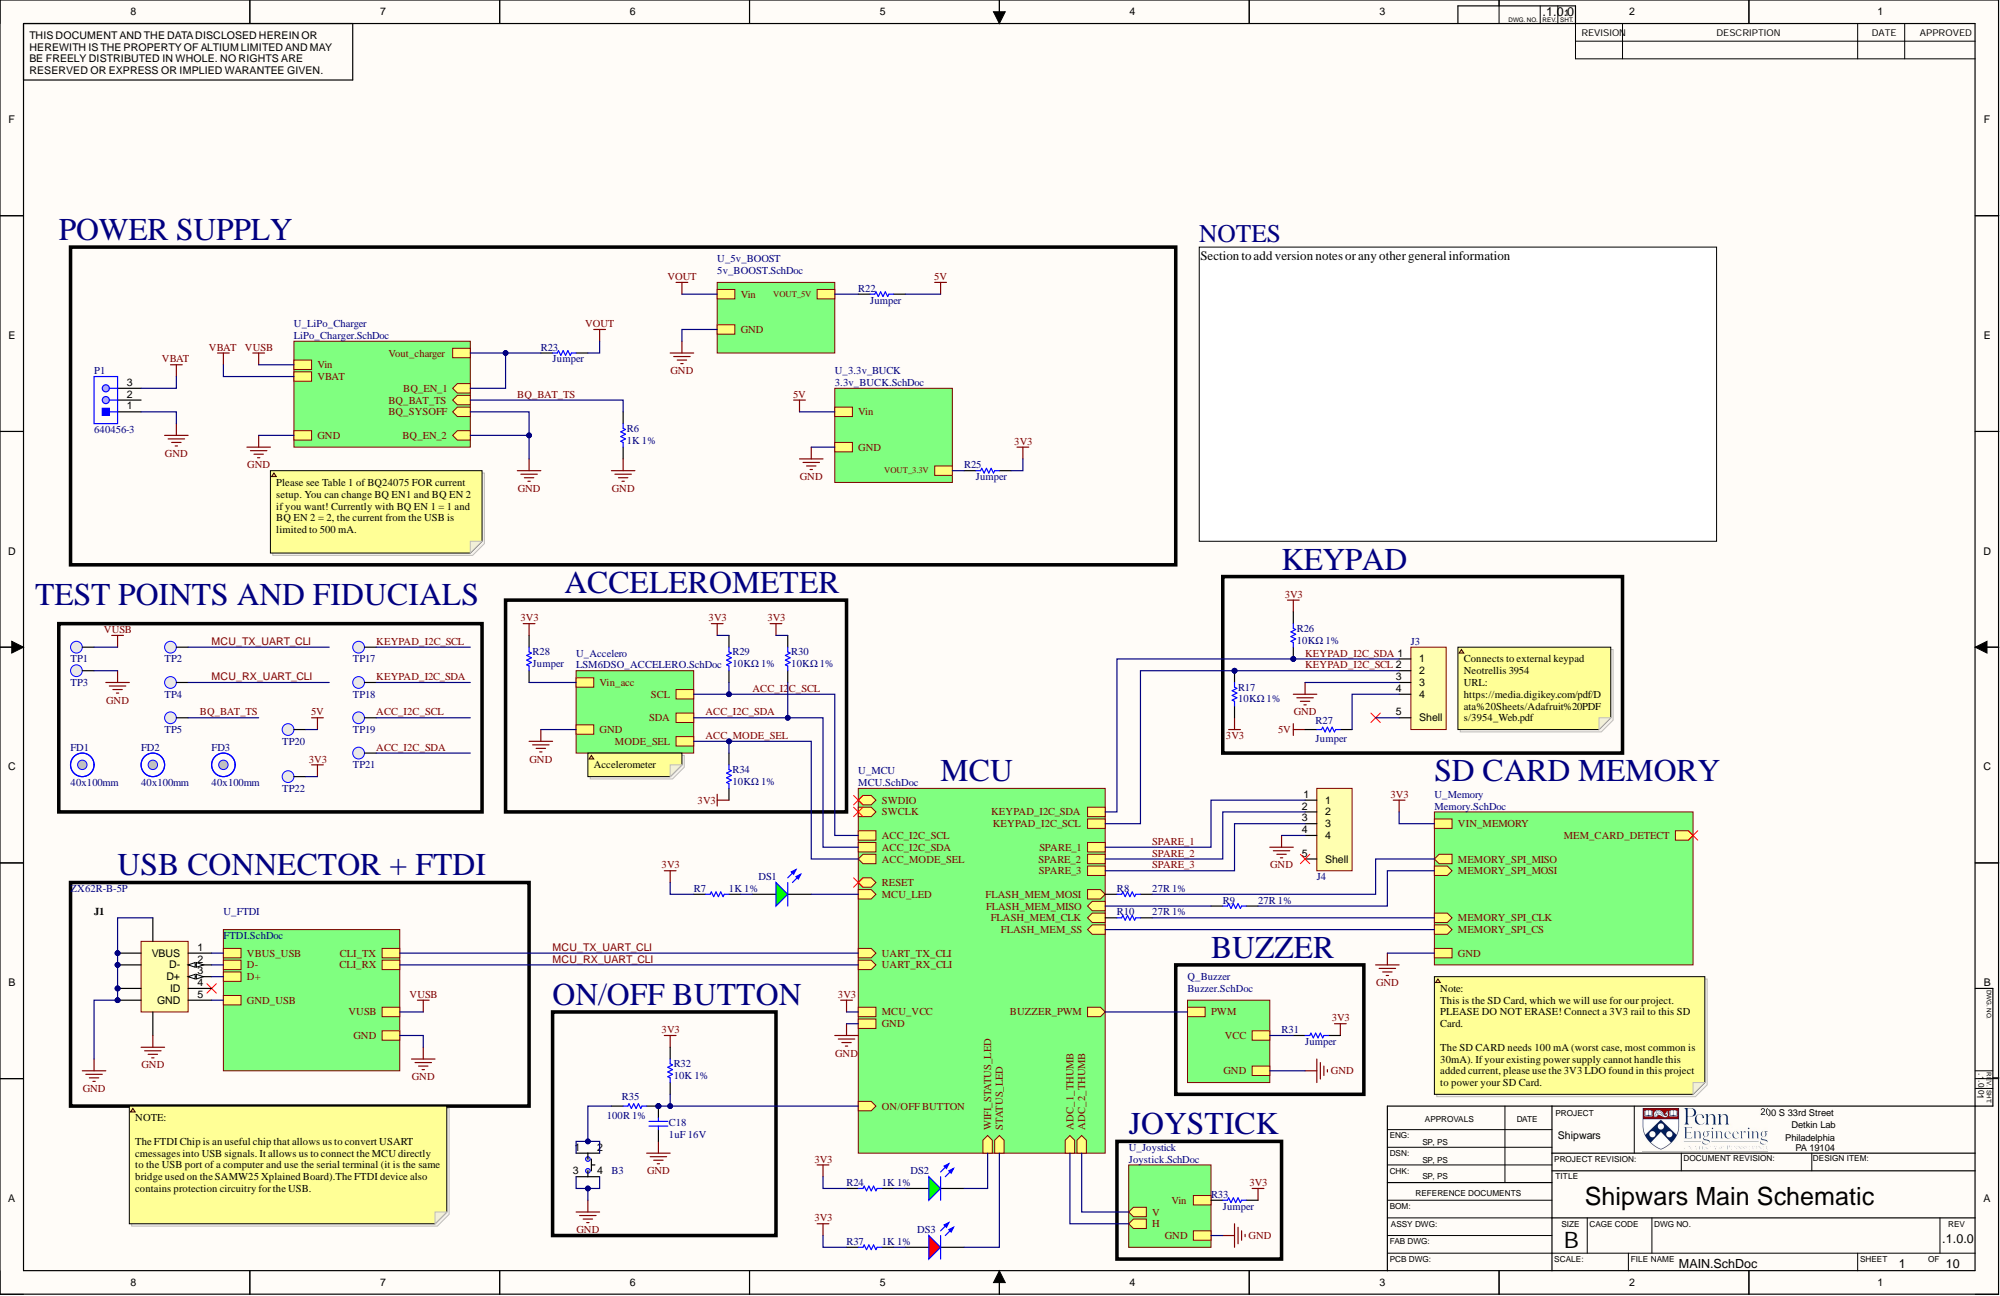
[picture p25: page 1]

DWG. NO. | REV. | SHT.

THIS DOCUMENT AND THE DATA DISCLOSED HEREIN OR HEREWITH IS THE PROPERTY OF ALTIUM LIMITED AND MAY BE FREELY DISTRIBUTED IN WHOLE. NO RIGHTS ARE RESERVED OR EXPRESS OR IMPLIED WARANTEE GIVEN. | NOTES | REVISION | DESCRIPTION | DATE | APPROVED

Section to add version notes or any other general information

GND
Please see Table 1 of BQ24075 FOR current
setup. You can change BQ EN1 and BQ EN 2
if you want! Currently with BQ EN 1 = 1 and
BQ EN 2 = 2, the current from the USB is
limited to 500 mA.

TEST POINTS AND FIDUCIALS

KEYPAD_I2C_SCL | 2 2

Connects to external keypad
Neotrellis 3954
URL:
https://media.digikey.com/pdf/D
ata%20Sheets/Adafruit%20PDF
s/3954_Web.pdf

Note:
This is the SD Card, which we will use for our project.
PLEASE DO NOT ERASE! Connect a 3V3 rail to this SD
Card.

REV. SHT. DWG. NO.

The SD CARD needs 100 mA (worst case, most common is
30mA). If your existing power supply cannot handle this
added current, please use the 3V3 LDO found in this project
to power your SD Card.

DATE | PROJECT Shipwars | 200 S 33rd Street Detkin Lab APPROVALS Philadelphia PA 19104

ENG: SP, PS

The FTDI Chip is an useful chip that allows us to convert USART
cmessages into USB signals. It allows us to connect the MCU directly
to the USB port of a computer and use the serial terminal (it is the same
bridge used on the SAMW25 Xplained Board).The FTDI device also
contains protection circuitry for the USB.

DSN: SP, PS

PROJECT REVISION: | DOCUMENT REVISION: | DESIGN ITEM:

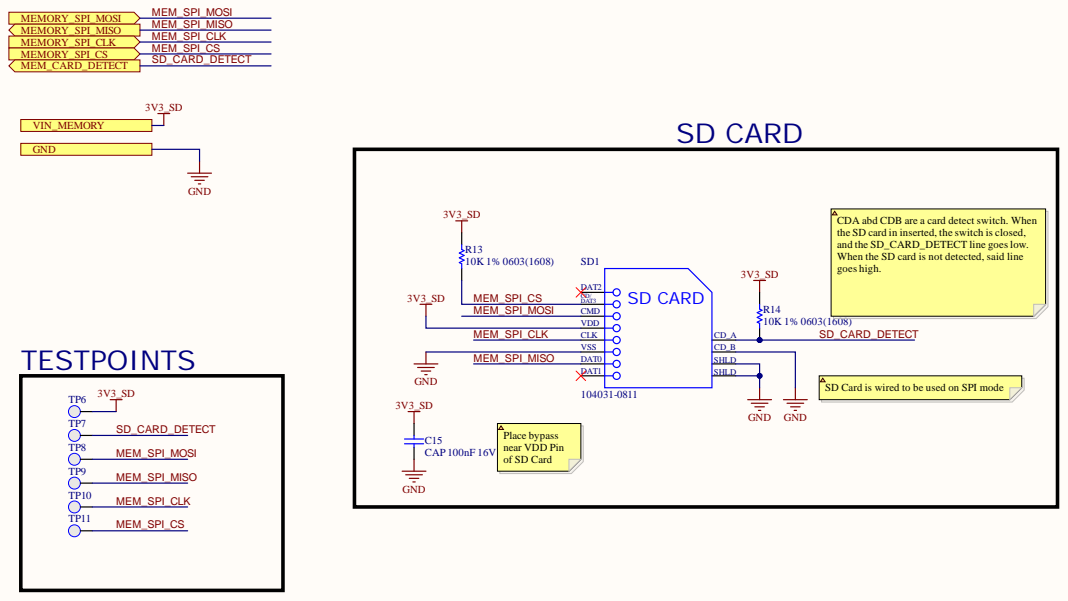
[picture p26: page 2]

DWG . N O . | R E V . | S T.

T IS DOC U MEN T AN D T HE ATA ISCLOSED HEREI N OR HEREW I T IS T HE PROPER TY OF ALT I U M LI M I TED AN M AY BE F REELY IST R IBU TED I N W HOLE. NO R IGH TS ARE RESERVED OR EXPRESS OR I MPLIED WARAN TEE GIVEN . | MEM_SPI MEMO RY _SPI_ M O S I MEM_SPI MEMO RY _SPI_ M I S O MEM_SPI MEMO RY _SPI_ C LK MEM_SPI MEMO RY _SPI_ C S SD_CAR MEM_CARD _ D E T E C T 3 V 3 _ S D SD CARD | REVISI O | N DESC R IPT I O N | DAT E | APPR OVED

REV. SHT. DWG. NO.

DATE | PRO JECT Shipw a rs | 2 0 0 S 3 3rd Stre e t b APPROVALS D e tki n L a Ph i l a d e l p h i a PA 1 9 1 0 4

ENG : SP, PS

DSN: SP, PS

PRO JECT REVISION: | DOCUMENT REVISION: | DESIGN ITEM :

CHK: SP, PS


DWG. NO. | REV. | SHT.

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

Calculation of crystal load capacitors:
Cext = 2x ( Ccrystal - Cpara - Cpcb )

ON/OFF BUTTON ON/OFF_BUTTON

Ccrystal = 12.5pF (from crystal
datasheet)
Cpara = 3.15pF (from MCU datasheet)
Cpcb = 0.5pF (estimate)

REV. SHT. DWG. NO.

DATE | PROJECT Shipwars | 200 S 33rd Street Detkin Lab APPROVALS Philadelphia PA 19104

ENG: SP, PS

DSN: SP, PS

PROJECT REVISION: | DOCUMENT REVISION: | DESIGN ITEM:

CHK: SP, PS


DWG. NO. | REV. | SHT.

THIS DOCUMENT AND THE DATA DISCLOSED HEREIN OR HEREWITH IS THE PROPERTY OF ALTIUM LIMITED AND MAY BE FREELY DISTRIBUTED IN WHOLE. NO RIGHTS ARE RESERVED OR EXPRESS OR IMPLIED WARANTEE GIVEN. | FTDI CHIP VCCIO

REV. SHT. DWG. NO.

DATE | PROJECT Shipwars | 200 S 33rd Street Detkin Lab APPROVALS Philadelphia PA 19104

ENG: SP, PS

DSN: SP, PS

PROJECT REVISION: | DOCUMENT REVISION: | DESIGN ITEM:

CHK: SP, PS


DWG . N O . | R V . | S T.

T IS DOC U MEN T AN T HE ATA ISCLOSED HEREI N OR HEREW I T IS T HE PROPER TY OF ALT I U M LI M I TED AN M AY BE REELY IST R IBU TED I N W HOLE. NO R IGH TS ARE RESERVED OR EXPRESS OR I MPLIED WARAN TEE GIVEN . | Vi n V b | REVISI O | N DESC R IPT I O N | DAT E | APPR OVED

1 K 1 3 1 % R2 0 BQ _ILIM

REV. SHT. DWG. NO.

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

ENG : SP, PS

DSN: SP, PS

PRO JECT REVISION: | DOCUMENT REVISION: | DESIGN ITEM :

CHK: SP, PS


DWG. NO. | REV. | SHT.

THIS DOCUMENT AND THE DATA DISCLOSED HEREIN OR HEREWITH IS THE PROPERTY OF ALTIUM LIMITED AND MAY BE FREELY DISTRIBUTED IN WHOLE. NO RIGHTS ARE RESERVED OR EXPRESS OR IMPLIED WARANTEE GIVEN. | VIN U2

PGND_2 7
PGND_3 5
PGND 6

TPS61032
VIN: 3.3V to 5V
OUT: 5V up to 2A
REF: https://webench.ti.com/appinfo/webench/scripts/SDP.cgi?ID=0929BF869665908F

REV. SHT. DWG. NO.

DATE | PROJECT Shipwars | 200 S 33rd Street Detkin Lab APPROVALS Philadelphia PA 19104

ENG: SP, PS

DSN: SP, PS
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

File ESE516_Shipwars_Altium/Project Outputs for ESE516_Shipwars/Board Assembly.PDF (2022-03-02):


DWG. NO.REV.SHT.

THIS DOCUMENT AND THE DATA DISCLOSED HEREIN OR HEREWITH IS THE PROPERTY OF ALTIUM LIMITED AND MAY BE FREELY DISTRIBUTED IN WHOLE. NO RIGHTS ARE RESERVED OR EXPRESS OR IMPLIED WARANTEE GIVEN.

Notes (Unless otherwise specified):

NOTES:
1. THIS ITEM IS ELECTROSTASTIC SENSITIVE
AND SHALL BE HANDLED ACCORDINGLY

APPROVALS | DATE

ENG: SP, PS | --/--/--
DSN: SP, PS | --/--/--
CHK: SP, PS | --/--/--


View from Top side (Scale 5:2)

JTAG Connector for programming

APPROVALS | DATE

ENG: SP, PS | --/--/--
DSN: SP, PS | --/--/--
CHK: SP, PS | --/--/--


View from Bottom side (Scale 5:2)

APPROVALS | DATE

ENG: SP, PS | --/--/--
DSN: SP, PS | --/--/--
CHK: SP, PS | --/--/--


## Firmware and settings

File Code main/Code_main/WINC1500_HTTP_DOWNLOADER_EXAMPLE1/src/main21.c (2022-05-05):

/**
 * @file      main.c
 * @brief     Main application entry point
 * @author    Eduardo Garcia
 * @date      2022-04-14
 * @copyright Copyright Bresslergroup\n
 *            This file is proprietary to Bresslergroup.
 *            All rights reserved. Reproduction or distribution, in whole
 *            or in part, is forbidden except by express written permission
 *            of Bresslergroup.
 ******************************************************************************/

/****
 * Includes
 ******************************************************************************/
#include <errno.h>

#include "CliThread/CliThread.h"
#include "ControlThread\ControlThread.h"
#include "FreeRTOS.h"
#include "IMU\lsm6dso_reg.h"
#include "SeesawDriver/Seesaw.h"
#include "SerialConsole.h"
#include "UiHandlerThread\UiHandlerThread.h"
#include "WifiHandlerThread/WifiHandler.h"
#include "asf.h"
#include "driver/include/m2m_wifi.h"
#include "main.h"
#include "stdio_serial.h"

/****
 * Defines and Types
 ******************************************************************************/
#define APP_TASK_ID 0 /**< @brief ID for the application task */
#define CLI_TASK_ID 1 /**< @brief ID for the command line interface task */

/****
 * Local Function Declaration
 ******************************************************************************/
void vApplicationIdleHook(void);
//!< Initial task used to initialize HW before other tasks are initialized
static void StartTasks(void);
void vApplicationDaemonTaskStartupHook(void);
void vApplicationStackOverflowHook(void);
void vApplicationMallocFailedHook(void);
void vApplicationTickHook(void);

/****
 * Variables
 ******************************************************************************/
static TaskHandle_t cliTaskHandle = NULL;      //!< CLI task handle
static TaskHandle_t daemonTaskHandle = NULL;   //!< Daemon task handle
static TaskHandle_t wifiTaskHandle = NULL;     //!< Wifi task handle
static TaskHandle_t uiTaskHandle = NULL;       //!< UI task handle
static TaskHandle_t controlTaskHandle = NULL;  //!< Control task handle

char bufferPrint[64];  ///< Buffer for daemon task

/**
 * @brief Main application function.
 * Application entry point.
 * @return int
 */
int main(void)

{
    /* Initialize the board. */
    system_init();

    /* Initialize the UART console. */
    InitializeSerialConsole();

    // Initialize trace capabilities
    vTraceEnable(TRC_START);
    // Start FreeRTOS scheduler
    vTaskStartScheduler();

    return 0;  // Will not get here
}

/**
 * function          vApplicationDaemonTaskStartupHook
 * @brief            Initialization code for all subsystems that require FreeRToS
 * @details			This function is called from the FreeRToS timer task. Any code
 *					here will be called before other tasks are initilized.
 * @param[in]        None
 * @return           None
 */
void vApplicationDaemonTaskStartupHook(void)
{
    SerialConsoleWriteString("\r\n\r\n-----ESE516 Main Program-----\r\n");

    // Initialize HW that needs FreeRTOS Initialization
    SerialConsoleWriteString("\r\n\r\nInitialize HW...\r\n");
    if (I2cInitializeDriver() != STATUS_OK) {
        SerialConsoleWriteString("Error initializing I2C Driver!\r\n");
    } else {
        SerialConsoleWriteString("Initialized I2C Driver!\r\n");
    }
	
	
    if (0 != InitializeSeesaw(NEO_TRELLIS_ADDR_1)) {
        SerialConsoleWriteString("Error initializing 1st Seesaw!\r\n");
    } else {
        SerialConsoleWriteString("Initialized 1st Seesaw!\r\n");
    }
	
	
	if (0 != InitializeSeesaw(NEO_TRELLIS_ADDR_2)) {
		SerialConsoleWriteString("Error initializing 2nd Seesaw!\r\n");
		} else {
		SerialConsoleWriteString("Initialized 2nd Seesaw!\r\n");
	}
	

    uint8_t whoamI = 0;
    (lsm6dso_device_id_get(GetImuStruct(), &whoamI));

    if (whoamI != LSM6DSO_ID) {
        SerialConsoleWriteString("Cannot find IMU!\r\n");
    } else {
        SerialConsoleWriteString("IMU found!\r\n");
        if (InitImu() == 0) {
            SerialConsoleWriteString("IMU initialized!\r\n");
        } else {
            SerialConsoleWriteString("Could not initialize IMU\r\n");
        }
    }

    StartTasks();

    vTaskSuspend(daemonTaskHandle);
}

/**
 * function          StartTasks
 * @brief            Initialize application tasks
 * @details
 * @param[in]        None
 * @return           None
 */
static void StartTasks(void)
{
    snprintf(bufferPrint, 64, "Heap before starting tasks: %d\r\n", xPortGetFreeHeapSize());
    SerialConsoleWriteString(bufferPrint);

    // Initialize Tasks here

    if (xTaskCreate(vCommandConsoleTask, "CLI_TASK", CLI_TASK_SIZE, NULL, CLI_PRIORITY, &cliTaskHandle) != pdPASS) {
        SerialConsoleWriteString("ERR: CLI task could not be initialized!\r\n");
    }

    snprintf(bufferPrint, 64, "Heap after starting CLI: %d\r\n", xPortGetFreeHeapSize());
    SerialConsoleWriteString(bufferPrint);

    if (xTaskCreate(vWifiTask, "WIFI_TASK", WIFI_TASK_SIZE, NULL, WIFI_PRIORITY, &wifiTaskHandle) != pdPASS) {
        SerialConsoleWriteString("ERR: WIFI task could not be initialized!\r\n");
    }
    snprintf(bufferPrint, 64, "Heap after starting WIFI: %d\r\n", xPortGetFreeHeapSize());
    SerialConsoleWriteString(bufferPrint);

    if (xTaskCreate(vUiHandlerTask, "UI Task", UI_TASK_SIZE, NULL, UI_TASK_PRIORITY, &uiTaskHandle) != pdPASS) {
        SerialConsoleWriteString("ERR: UI task could not be initialized!\r\n");
    }

    snprintf(bufferPrint, 64, "Heap after starting UI Task: %d\r\n", xPortGetFreeHeapSize());
    SerialConsoleWriteString(bufferPrint);

    if (xTaskCreate(vControlHandlerTask, "Control Task", CONTROL_TASK_SIZE, NULL, CONTROL_TASK_PRIORITY, &controlTaskHandle) != pdPASS) {
        SerialConsoleWriteString("ERR: Control task could not be initialized!\r\n");
    }
    snprintf(bufferPrint, 64, "Heap after starting Control Task: %d\r\n", xPortGetFreeHeapSize());
    SerialConsoleWriteString(bufferPrint);
}



void vApplicationMallocFailedHook(void)
{
    SerialConsoleWriteString("Error on memory allocation on FREERTOS!\r\n");
    while (1)
        ;
}

void vApplicationStackOverflowHook(void)
{
    SerialConsoleWriteString("Error on stack overflow on FREERTOS!\r\n");
    while (1)
        ;
}

#include "MCHP_ATWx.h"
void vApplicationTickHook(void)
{
    SysTick_Handler_MQTT();
}

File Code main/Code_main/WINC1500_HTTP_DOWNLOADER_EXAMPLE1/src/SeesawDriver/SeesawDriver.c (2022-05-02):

/**
 * @file      Seesaw.c
 * @brief     Driver for the seesaw 4x4 LED button from Adafruit. See https://cdn-learn.adafruit.com/downloads/pdf/adafruit-seesaw-atsamd09-breakout.pdf
  and https://github.com/adafruit/Adafruit_Seesaw

 * @author    Eduardo Garcia
 * @date      2020-01-01

 ******************************************************************************/

#include "I2cDriver/I2cDriver.h"
#include "Seesaw.h"
#include "SerialConsole.h"

/******************************************************************************
 * Includes
 ******************************************************************************/

/******************************************************************************
 * Defines
 ******************************************************************************/

/******************************************************************************
 * Variables
 ******************************************************************************/
I2C_Data seesawData;  ///< Global variable to use for I2C communications with the Seesaw Device
/******************************************************************************
 * Forward Declarations
 ******************************************************************************/
const uint8_t msgBaseGetHWID[2] = {SEESAW_STATUS_BASE, SEESAW_STATUS_HW_ID};                                              ///< Message to get HW ID from
const uint8_t msgNeopixelPin[3] = {SEESAW_NEOPIXEL_BASE, SEESAW_NEOPIXEL_PIN, NEO_TRELLIS_NEOPIX_PIN};                    ///< Message to set Neopixel to a PORTA pin
const uint8_t msgNeopixelSpeed[3] = {SEESAW_NEOPIXEL_BASE, SEESAW_NEOPIXEL_SPEED, 0x01};                                  ///< Message to set neopixel speed
const uint8_t msgNeopixelBufLength[4] = {SEESAW_NEOPIXEL_BASE, SEESAW_NEOPIXEL_BUF_LENGTH, 0, NEO_TRELLIS_NUM_KEYS * 3};  ///< Message to tell Seesaw the number of neopixels

const uint8_t msgKeypadEnableInt[3] = {SEESAW_KEYPAD_BASE, SEESAW_KEYPAD_INTENSET, 0x01};  ///< Message to enable Keypad Interrupts
const uint8_t msgKeypadGetCount[2] = {SEESAW_KEYPAD_BASE, SEESAW_KEYPAD_COUNT};            ///< Get count of active events
/******************************************************************************
 * Callback Functions
 ******************************************************************************/

static void SeesawTurnOnLedTest(uint8_t neotrellis_addr);
static void SeesawInitializeKeypad(uint8_t neotrellis_addr);
/******************************************************************************
 * Functions
 ******************************************************************************/

/**
 * @fn		int InitializeSeesaw(void)
 * @brief	Initializes the Seesaw 4x4
 * @details 	Assumes I2C is already initialized

 * @return		Returns 0 if no errors.
 * @note
 */
int InitializeSeesaw(uint8_t neotrellis_addr)
{
    uint8_t readData[2];
    seesawData.address = neotrellis_addr;
    seesawData.msgOut = &msgBaseGetHWID[0];
    seesawData.lenOut = sizeof(msgBaseGetHWID);
    seesawData.msgIn = &readData[0];
    seesawData.lenIn = 1;

    // Check if device is on the line - it should answer with its HW ID

    int error = I2cReadDataWait(&seesawData, 0, 100);

    if (ERROR_NONE != error) {
        SerialConsoleWriteString("Error initializing Seesaw!/r/n");
    } else {
        if (readData[0] != SEESAW_HW_ID_CODE) {
            SerialConsoleWriteString("Error/r/n");
        } else {
            SerialConsoleWriteString("Found Seesaw!/r/n");
        }
    }

    // Tell the Seesaw which pins to use
    seesawData.msgOut = &msgNeopixelPin[0];
    seesawData.lenOut = sizeof(msgNeopixelPin);

    error = I2cWriteDataWait(&seesawData, 100);
    if (ERROR_NONE != error) {
        SerialConsoleWriteString("Could not write Seesaw pin!/r/n");
    }

    // Set seesaw Neopixel speed
    seesawData.msgOut = &msgNeopixelSpeed[0];
    seesawData.lenOut = sizeof(msgNeopixelSpeed);

    error = I2cWriteDataWait(&seesawData, 100);
    if (ERROR_NONE != error) {
        SerialConsoleWriteString("Could not set seesaw Neopixel speed!/r/n");
    }

    // Set seesaw Neopixel number of devices
    seesawData.msgOut = &msgNeopixelBufLength[0];
    seesawData.lenOut = sizeof(msgNeopixelBufLength);

    error = I2cWriteDataWait(&seesawData, 100);
    if (ERROR_NONE != error) {
        SerialConsoleWriteString("Could not set seesaw Neopixel number of devices/r/n");
    }

    SeesawTurnOnLedTest(neotrellis_addr);

    SeesawInitializeKeypad(neotrellis_addr);
    return error;
}

/**
 * @fn		uint8_t SeesawGetKeypadCount(void)
 * @brief	Returns the number of key events currently on the Seesaw Keypad
 * @details 	Assumes Seesaw is already initialized

 * @return		Returns the number of events in the buffer. Use SeesawReadKeypad to read these events.
 * @note
*/
uint8_t SeesawGetKeypadCount(uint8_t neotrellis_addr)
{
    uint8_t count = 0;
    seesawData.address = neotrellis_addr;
    seesawData.msgOut = &msgKeypadGetCount[0];
    seesawData.lenOut = sizeof(msgKeypadGetCount);
    seesawData.msgIn = &count;
    seesawData.lenIn = 1;

    int error = I2cReadDataWait(&seesawData, 0, 100);

    if (ERROR_NONE != error) {
        SerialConsoleWriteString("Error reading Seesaw counts!/r/n");
		return 99;
    }
    return count;
}

/**
 * @fn		int32_t SeesawReadKeypad(uint8_t *buffer, uint8_t count)
 * @brief	Returns the number of requested events in the Seesaw FIFO buffer into the buffer variable
 * @param[out] buffer  Pointer to a buffer where the function will write the events in the seesaw buffer to.
 * @param[in]  count  Number of events to read from the Seesaw FIFO

 * @return		Returns zero if no I2C errors occurred. Other number in case of error
 * @note         Use SeesawGetKeypadCount to know how many events are in buffer.
*/
int32_t SeesawReadKeypad(uint8_t neotrellis_addr, uint8_t *buffer, uint8_t count)
{
    if (count == 0) return ERROR_NONE;
    uint8_t cmd[] = {SEESAW_KEYPAD_BASE, SEESAW_KEYPAD_FIFO};
    seesawData.address = neotrellis_addr;
    seesawData.msgOut = (const uint8_t*) &cmd[0];
    seesawData.lenOut = sizeof(cmd);
    seesawData.msgIn = buffer;
    seesawData.lenIn = count;

    int error = I2cReadDataWait(&seesawData, 0, 100);

    if (ERROR_NONE != error) {
        SerialConsoleWriteString("Error reading Seesaw counts!/r/n");
    }
    return error;
}
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

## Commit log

2022-02-01 add relavent files
    [Current_BOM.xlsx]
2022-02-03 Added main components
    [Current_BOM.xlsx, Main_PCBLIB.PcbLib, Main_SCBLIB.SchLib]
2022-02-04 added all main components etc.
    [3.3v_BUCK.SchDoc, 5v_BOOST.SchDoc, Buzzer.SchDoc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]
2022-02-04 update a bit
    [Buzzer.SchDoc, LSM6DSO_ACCELERO.SchDoc, MAIN.SchDoc]
2022-02-04 something changed?
    [MAIN.SchDoc]
2022-02-11 A2 update
    [3.3v_BUCK.SchDoc, 5v_BOOST.SchDoc, Buzzer.SchDoc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]
2022-02-12 update joystick etc.
    [3.3v_BUCK.SchDoc, 5v_BOOST.SchDoc, Joystick.SchDoc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]
2022-02-12 seperate SD
    [MAIN.SchDoc]
2022-02-14 Capacitors and Resistors BOM
2022-02-14 LEDs and Spares Connector
    [MAIN.SchDoc, MCU.SchDoc, Memory.SchDoc]
2022-02-15 A2 Feedback
    [MAIN.SchDoc, MCU.SchDoc]
2022-02-15 after OH
    [3.3v_BUCK.SchDoc, 5v_BOOST.SchDoc, Buzzer.SchDoc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]
2022-02-16 Template + I2C second channel
    [Buzzer.SchDoc, MAIN.SchDoc, MCU.SchDoc]
2022-02-16 updated some components
    [3.3v_BUCK.SchDoc, 5v_BOOST.SchDoc, Buzzer.SchDoc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]
2022-02-16 Nothing important
    [ShipWarsBoM.xlsx]
2022-02-21 import component into pcbs
    [ESE516_shipwars_PCB.PcbDoc]
2022-02-22 midpoint update
    [3.3v_BUCK.SchDoc, 5v_BOOST.SchDoc, ESE516_Shipwars.PrjPcb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]
2022-02-22 pcb layout put in
    [ESE516_shipwars_PCB.PcbDoc, MAIN.SchDoc]
2022-02-22 partial routing
    [ESE516_shipwars_PCB.PcbDoc]
2022-02-22 change layout
    [ESE516_shipwars_PCB.PcbDoc]
2022-02-23 routing done (no polygons)
    [ESE516_shipwars_PCB.PcbDoc]
2022-02-23 final routing + power polygons
2022-02-23 before submission
    [ESE516_Shipwars.PrjPcb, ESE516_shipwars_PCB.PcbLib]
2022-02-24 add polygon pour on pcb
2022-02-26 partial feedback implementation
    [3.3v_BUCK.SchDoc, LSM6DSO_ACCELERO.SchDoc, MAIN.SchDoc]
2022-02-26 feedback implementations except accel
    [Joystick.SchDoc, LSM6DSO_ACCELERO.SchDoc]
2022-02-27 fixes from A4
    [Joystick.SchDoc, LSM6DSO_ACCELERO.SchDoc]
2022-02-28 added team name etc.
    [3.3v_BUCK.SchDoc, 5v_BOOST.SchDoc, Buzzer.SchDoc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]
2022-03-02 Final PCB (ready to order)
2022-03-03 update B4 compile & order
    [BOM_notes.xlsx]
2022-03-03 output files
    [ESE516_shipwars_PCB.GBL, ESE516_shipwars_PCB.GBO, ESE516_shipwars_PCB.GBP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]
2022-03-04 ready to order
    [PCBNG BOM-ESE516_Shipwars_BOM(Build_Alt).xlsx, Pick Place for ESE516_shipwars_PCB(Build_Alt).csv]
2022-04-29 add code for PCB
2022-04-30 add shtc sensor code!
2022-05-05 not done yet (bootloader error?)
    [WifiHandler.c, WifiHandler.h]
